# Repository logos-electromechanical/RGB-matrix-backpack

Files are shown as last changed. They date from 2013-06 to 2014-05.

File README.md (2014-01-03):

Logos RGB Matrix Backpack firmware, examples and docs
---------------------------

With the default firmware, this backpack is a board for driving 8x8 common anode RGB LED matrices from the I2C bus.

Remember that firmware memory is precious - you have *2 KB* of EEPROM and *128 bytes* of SRAM to work with on the backpack itself.

**Compilers:**

* AVR firmware is compiled with [WinAVR v20100110](http://sourceforge.net/projects/winavr/)

* Examples are compiled with [the Arduino IDE](http://arduino.cc/en/main/software)

**Hardware info:**

* [Holtek LED driver - HT1632C data sheet, FAQs and app notes](http://www.holtek.com/english/docum/consumer/1632c.htm)
	
* [Atmel MCU - ATtiny 2313V data sheet](http://www.atmel.com/Images/doc2543.pdf)

* [RGB LED common anode 8x8 matrix - ORM 2088RGB-5 data sheet](http://selfbuilt.net/datasheets/2088RGB-5-datasheet.jpg)

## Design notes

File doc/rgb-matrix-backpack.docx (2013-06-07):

| 9/28/2012

RGB LED Matrix I2C Backpack

Drive an 8x8 matrix of RGB LEDs over I2C
| | | Logos Electromechanical

# RGB LED Matrix I2C Backpack

Drive an 8x8 matrix of RGB LEDs over I2C

# Introduction

We recently found a good source of cheap 8x8 RGB LED common anode matrix displays. However, these displays have thirty-two pins (8 common anodes and 24 cathodes), which makes them painful to wire. Displaying any sort of image requires multiplexing, which consumes processor resources and programming time. We needed a better solution.

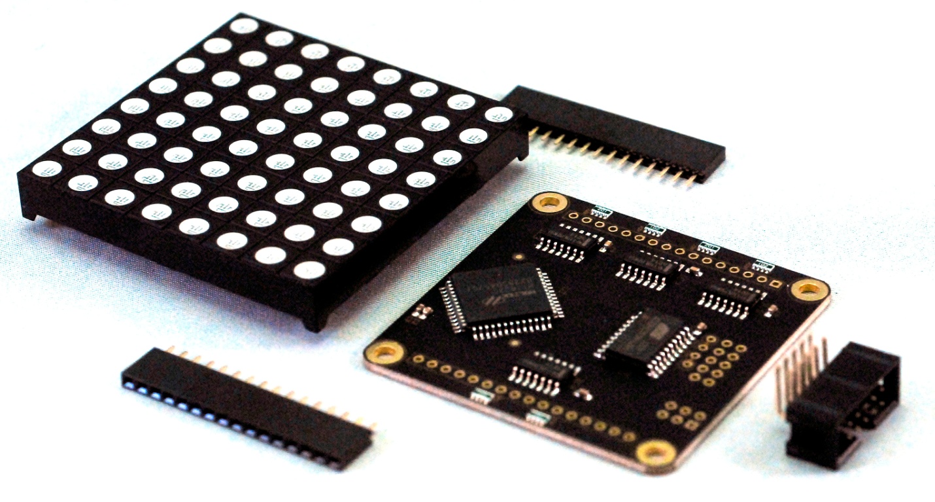
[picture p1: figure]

We were able to find a great driver chip that performs all of the required matrix functions. However, it speaks a strange dialect of SPI. Therefore, we added an ATtiny 2313 to provide an I2C interface that you can talk to with an Arduino or other microcontroller that has an I2C interface.

# Board Overview

The board contains eight integrated circuits – the ATtiny (U2) , the main driver chip (U1) and four hex inverters (IC1 – IC4) for driving the rows. The I2C interface connector solders on to the back of the board in order to avoid interfering with the display mounted to the front.

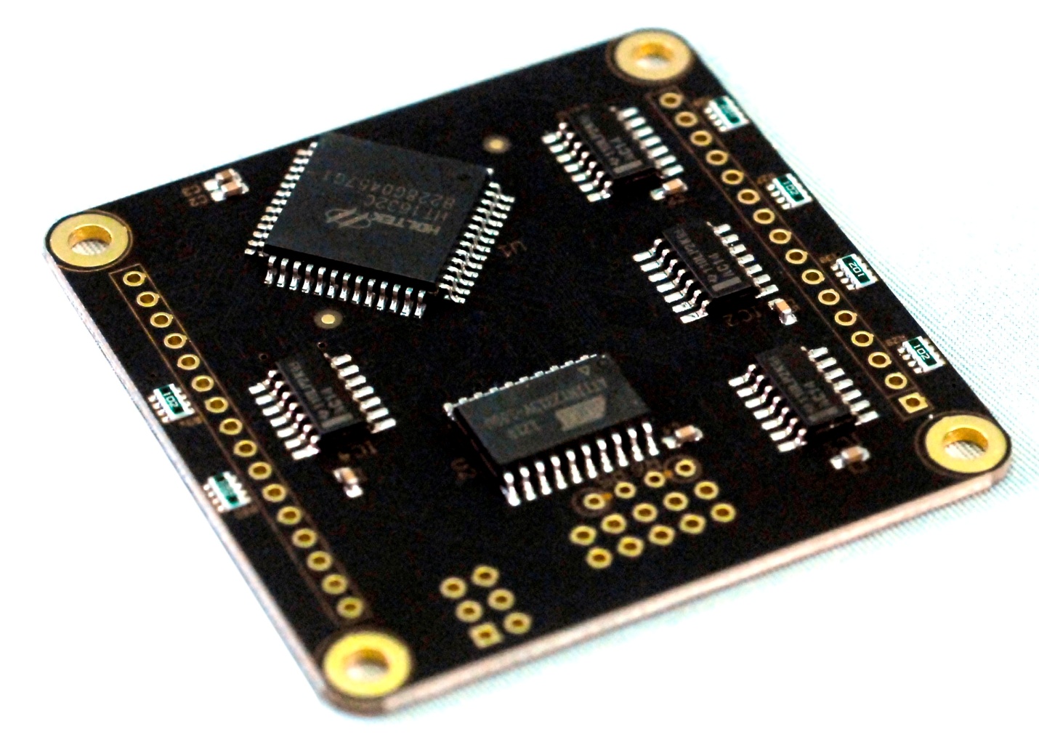
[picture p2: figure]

# Board Usage

## Assembly

- Insert the two sixteen pin female headers into the top (component) side of the board. This is most easily accomplished by plugging them into the RGB array and using that to align them upright. Solder them in place.
- Insert the ten pin male shrouded header into the back (no components) side of the board and solder it in place.
- Set the address as described below.

## Cable Pinout

The cable pinout is called out on the back side of the board. It is designed to interface with the line of I2C boards made by Snoot Labs, and therefore contains some pins that are extraneous to the use of this board.

Pin # | Pin Name | Pin Function
1-3 | 5V | Logic and LED power
4,6,8 | GND | Ground
5 | SDA | I2C Data
7 | SCL | I2C Clock
9-10 | 3V3 | Not connected

## Address Selection

The address is selected by the six jumpers on the back of the board. Depending on the desired value, the center terminal should be connected via a solder jumper to either the left (1) or right (0) terminal. These control the bottom six bits of the seven bit I2C address. The upper bit is always 1. Therefore, the possible I2C addresses range from binary b1000000 (hex 0x40) to binary b1111111 (hex 0x7f). If any jumper is left unmade, it defaults to a 1. Therefore, the default address of an otherwise un-configured board is 0x7f.

## Communication

Communication with the board is straightforward – send 24 bytes to the board over I2C. Each byte controls a single row of a single color. The first eight bytes control the red LEDs, the second eight bytes control the green LEDs, and the last eight bytes control the blue LEDs. The typical communication code under Arduino looks like this:

byte data[24];

Wire.beginTransmission(ADDRESS);

Wire.write(data, 24);

Wire.endTransmission();

This will transmit the contents of data to the board located at ADDRESS. The mapping of the transmitted bytes to the LEDs is as follows. Column numbers from the left, row numbers from the top.

Byte | MSB | Bit 6 | Bit 5 | Bit 4 | Bit 3 | Bit 2 | Bit 1 | LSB
0 | Red(0,0) | Red(1,0) | Red(2,0) | Red(3,0) | Red(4,0) | Red(5,0) | Red(6,0) | Red(7,0)
1 | Red(0,1) | Red(1,1) | Red(2,1) | Red(3,1) | Red(4,1) | Red(5,1) | Red(6,1) | Red(7,1)
2 | Red(0,2) | Red(1,2) | Red(2,2) | Red(3,2) | Red(4,2) | Red(5,2) | Red(6,2) | Red(7,2)
3 | Red(0,3) | Red(1,3) | Red(2,3) | Red(3,3) | Red(4,3) | Red(5,3) | Red(6,3) | Red(7,3)
4 | Red(0,4) | Red(1,4) | Red(2,4) | Red(3,4) | Red(4,4) | Red(5,4) | Red(6,4) | Red(7,4)
5 | Red(0,5) | Red(1,5) | Red(2,5) | Red(3,5) | Red(4,5) | Red(5,5) | Red(6,5) | Red(7,5)
6 | Red(0,6) | Red(1,6) | Red(2,6) | Red(3,6) | Red(4,6) | Red(5,6) | Red(6,6) | Red(7,6)
7 | Red(0,7) | Red(1,7) | Red(2,7) | Red(3,7) | Red(4,7) | Red(5,7) | Red(6,7) | Red(7,7)
8 | Green(0,7) | Green(1,7) | Green(2,7) | Green(3,7) | Green(4,7) | Green(5,7) | Green(6,7) | Green(7,7)
9 | Green(0,6) | Green(1,6) | Green(2,6) | Green(3,6) | Green(4,6) | Green(5,6) | Green(6,6) | Green(7,6)
10 | Green(0,5) | Green(1,5) | Green(2,5) | Green(3,5) | Green(4,5) | Green(5,5) | Green(6,5) | Green(7,5)
11 | Green(0,4) | Green(1,4) | Green(2,4) | Green(3,4) | Green(4,4) | Green(5,4) | Green(6,4) | Green(7,4)
12 | Green(0,3) | Green(1,3) | Green(2,3) | Green(3,3) | Green(4,3) | Green(5,3) | Green(6,3) | Green(7,3)
13 | Green(0,2) | Green(1,2) | Green(2,2) | Green(3,2) | Green(4,2) | Green(5,2) | Green(6,2) | Green(7,2)
13 | Green(0,1) | Green(1,1) | Green(2,1) | Green(3,1) | Green(4,1) | Green(5,1) | Green(6,1) | Green(7,1)
15 | Green(0,0) | Green(1,0) | Green(2,0) | Green(3,0) | Green(4,0) | Green(5,0) | Green(6,0) | Green(7,0)
16 | Blue(0,0) | Blue(1,0) | Blue(2,0) | Blue(3,0) | Blue(4,0) | Blue(5,0) | Blue(6,0) | Blue(7,0)
17 | Blue(0,1) | Blue(1,1) | Blue(2,1) | Blue(3,1) | Blue(4,1) | Blue(5,1) | Blue(6,1) | Blue(7,1)
18 | Blue(0,2) | Blue(1,2) | Blue(2,2) | Blue(3,2) | Blue(4,2) | Blue(5,2) | Blue(6,2) | Blue(7,2)
19 | Blue(0,3) | Blue(1,3) | Blue(2,3) | Blue(3,3) | Blue(4,3) | Blue(5,3) | Blue(6,3) | Blue(7,3)
20 | Blue(0,4) | Blue(1,4) | Blue(2,4) | Blue(3,4) | Blue(4,4) | Blue(5,4) | Blue(6,4) | Blue(7,4)
21 | Blue(0,5) | Blue(1,5) | Blue(2,5) | Blue(3,5) | Blue(4,5) | Blue(5,5) | Blue(6,5) | Blue(7,5)
22 | Blue(0,6) | Blue(1,6) | Blue(2,6) | Blue(3,6) | Blue(4,6) | Blue(5,6) | Blue(6,6) | Blue(7,6)
23 | Blue(0,7) | Blue(1,7) | Blue(2,7) | Blue(3,7) | Blue(4,7) | Blue(5,7) | Blue(6,7) | Blue(7,7)

4 © 2010 Logos Electromechanical CC-BY-NC-ND 3.0

5 © 2010 Logos Electromechanical CC-BY-NC-ND 3.0

Logos Electromechanical

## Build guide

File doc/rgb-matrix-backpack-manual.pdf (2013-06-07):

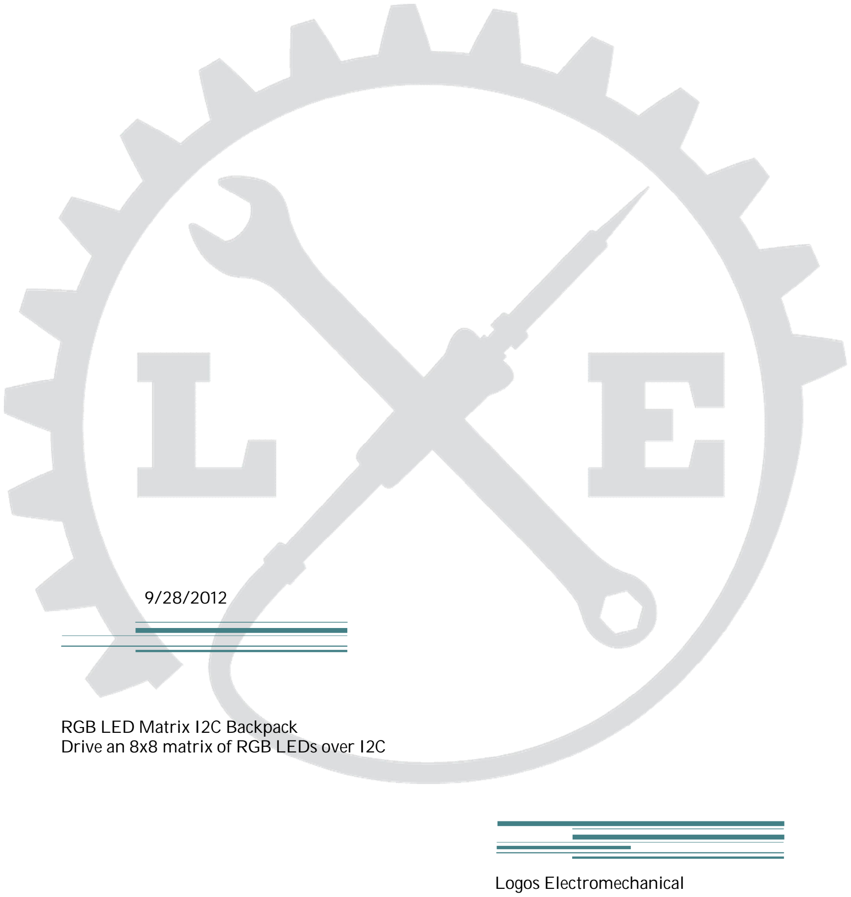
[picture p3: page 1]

9/28/2012

RGB LED Matrix I2C Backpack
Drive an 8x8 matrix of RGB LEDs over I2C

Logos Electromechanical

Logos Electromechanical

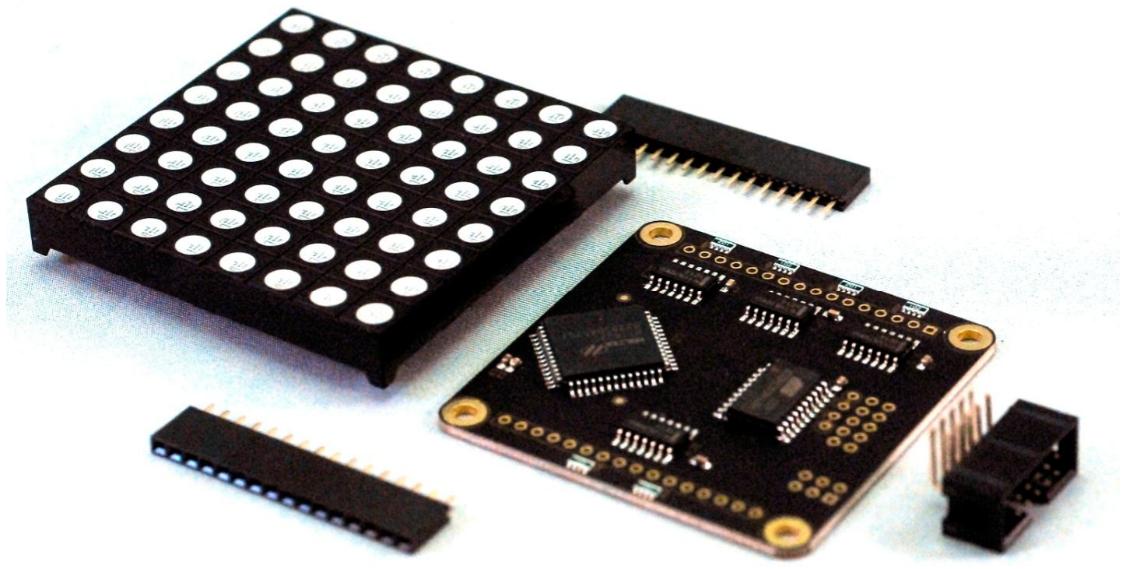
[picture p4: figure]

1

© 2010 Logos Electromechanical CC-BY-NC-ND 3.0

# RGB LED Matrix I2C Backpack

Drive an 8x8 matrix of RGB LEDs over I2C

## Introduction

We recently found a good source of cheap 8x8 RGB LED common anode matrix

displays. However, these displays have thirty-two pins (8 common anodes and 24

cathodes), which makes them painful to wire. Displaying any sort of image requires

multiplexing, which consumes processor resources and programming time. We needed

a better solution.

We were able to find a great driver chip that performs all of the required matrix

functions. However, it speaks a strange dialect of SPI. Therefore, we added an ATtiny

2313 to provide an I2C interface that you can talk to with an Arduino or other

microcontroller that has an I2C interface.

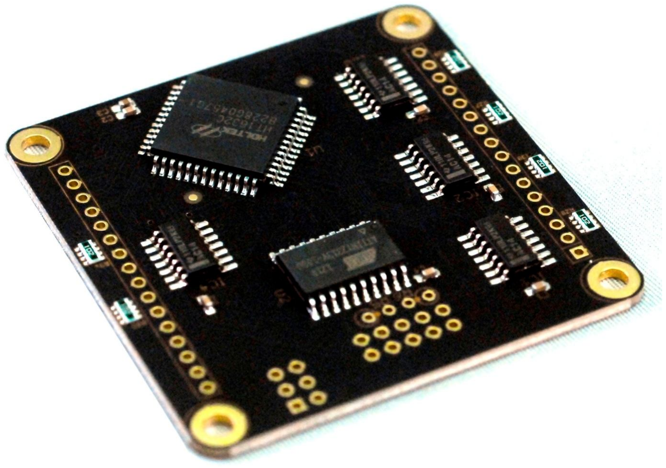
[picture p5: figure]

2

## Board Overview

The board contains eight integrated circuits – the ATtiny (U2) , the main driver chip

(U1) and four hex inverters (IC1 – IC4) for driving the rows. The I2C interface connector

solders on to the back of the board in order to avoid interfering with the display

mounted to the front.

3

## Board Usage

Assembly

- Insert the two sixteen pin female headers into the top (component) side of the

board. This is most easily accomplished by plugging them into the RGB array and

using that to align them upright. Solder them in place.

- Insert the ten pin male shrouded header into the back (no components) side of

the board and solder it in place.

- Set the address as described below.

Cable Pinout

The cable pinout is called out on the back side of the board. It is designed to interface

with the line of I2C boards made by Snoot Labs, and therefore contains some pins that

are extraneous to the use of this board.

Pin # | Pin Name | Pin Function
1-3 | 5V | Logic and LED power
4,6,8 | GND | Ground
5 | SDA | I2C Data
7 | SCL | I2C Clock
9-10 | 3V3 | Not connected

Address Selection

The address is selected by the six jumpers on the back of the board. Depending on the

desired value, the center terminal should be connected via a solder jumper to either the

left (1) or right (0) terminal. These control the bottom six bits of the seven bit I2C

address. The upper bit is always 1. Therefore, the possible I2C addresses range from

binary b1000000 (hex 0x40) to binary b1111111 (hex 0x7f). If any jumper is left unmade,

4

it defaults to a 1. Therefore, the default address of an otherwise un-configured board is

0x7f.

Communication

Communication with the board is straightforward – send 24 bytes to the board over I2C.

Each byte controls a single row of a single color. The first eight bytes control the red

LEDs, the second eight bytes control the green LEDs, and the last eight bytes control the

blue LEDs. The typical communication code under Arduino looks like this:

byte data[24];

Wire.beginTransmission(ADDRESS);

Wire.write(data, 24);

Wire.endTransmission();

This will transmit the contents of data to the board located at ADDRESS. The mapping

of the transmitted bytes to the LEDs is as follows. Column numbers from the left, row

numbers from the top.

Byte MSB | Bit 6 | Bit 5 | Bit 4 | Bit 3 | Bit 2 | Bit 1 | LSB
0 | Red(0,0) | Red(1,0) | Red(2,0) | Red(3,0) | Red(4,0) | Red(5,0) | Red(6,0) | Red(7,0)
1 | Red(0,1) | Red(1,1) | Red(2,1) | Red(3,1) | Red(4,1) | Red(5,1) | Red(6,1) | Red(7,1)
2 | Red(0,2) | Red(1,2) | Red(2,2) | Red(3,2) | Red(4,2) | Red(5,2) | Red(6,2) | Red(7,2)
3 | Red(0,3) | Red(1,3) | Red(2,3) | Red(3,3) | Red(4,3) | Red(5,3) | Red(6,3) | Red(7,3)
4 | Red(0,4) | Red(1,4) | Red(2,4) | Red(3,4) | Red(4,4) | Red(5,4) | Red(6,4) | Red(7,4)
5 | Red(0,5) | Red(1,5) | Red(2,5) | Red(3,5) | Red(4,5) | Red(5,5) | Red(6,5) | Red(7,5)
6 | Red(0,6) | Red(1,6) | Red(2,6) | Red(3,6) | Red(4,6) | Red(5,6) | Red(6,6) | Red(7,6)
7 | Red(0,7) | Red(1,7) | Red(2,7) | Red(3,7) | Red(4,7) | Red(5,7) | Red(6,7) | Red(7,7)
8 | Green(0,7) Green(1,7) Green(2,7) Green(3,7) Green(4,7) Green(5,7) Green(6,7) Green(7,7)

5

Byte MSB | Bit 6 | Bit 5 | Bit 4 | Bit 3 | Bit 2 | Bit 1 | LSB
9 | Green(0,6) Green(1,6) Green(2,6) Green(3,6) Green(4,6) Green(5,6) Green(6,6) Green(7,6)
10 | Green(0,5) Green(1,5) Green(2,5) Green(3,5) Green(4,5) Green(5,5) Green(6,5) Green(7,5)
11 | Green(0,4) Green(1,4) Green(2,4) Green(3,4) Green(4,4) Green(5,4) Green(6,4) Green(7,4)
12 | Green(0,3) Green(1,3) Green(2,3) Green(3,3) Green(4,3) Green(5,3) Green(6,3) Green(7,3)
13 | Green(0,2) Green(1,2) Green(2,2) Green(3,2) Green(4,2) Green(5,2) Green(6,2) Green(7,2)
13 | Green(0,1) Green(1,1) Green(2,1) Green(3,1) Green(4,1) Green(5,1) Green(6,1) Green(7,1)
15 | Green(0,0) Green(1,0) Green(2,0) Green(3,0) Green(4,0) Green(5,0) Green(6,0) Green(7,0)
16 | Blue(0,0) | Blue(1,0) | Blue(2,0) | Blue(3,0) | Blue(4,0) | Blue(5,0) | Blue(6,0) | Blue(7,0)
17 | Blue(0,1) | Blue(1,1) | Blue(2,1) | Blue(3,1) | Blue(4,1) | Blue(5,1) | Blue(6,1) | Blue(7,1)
18 | Blue(0,2) | Blue(1,2) | Blue(2,2) | Blue(3,2) | Blue(4,2) | Blue(5,2) | Blue(6,2) | Blue(7,2)
19 | Blue(0,3) | Blue(1,3) | Blue(2,3) | Blue(3,3) | Blue(4,3) | Blue(5,3) | Blue(6,3) | Blue(7,3)
20 | Blue(0,4) | Blue(1,4) | Blue(2,4) | Blue(3,4) | Blue(4,4) | Blue(5,4) | Blue(6,4) | Blue(7,4)
21 | Blue(0,5) | Blue(1,5) | Blue(2,5) | Blue(3,5) | Blue(4,5) | Blue(5,5) | Blue(6,5) | Blue(7,5)
22 | Blue(0,6) | Blue(1,6) | Blue(2,6) | Blue(3,6) | Blue(4,6) | Blue(5,6) | Blue(6,6) | Blue(7,6)
23 | Blue(0,7) | Blue(1,7) | Blue(2,7) | Blue(3,7) | Blue(4,7) | Blue(5,7) | Blue(6,7) | Blue(7,7)

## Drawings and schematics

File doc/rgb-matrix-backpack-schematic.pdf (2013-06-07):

## ABCDE

## ABCDE

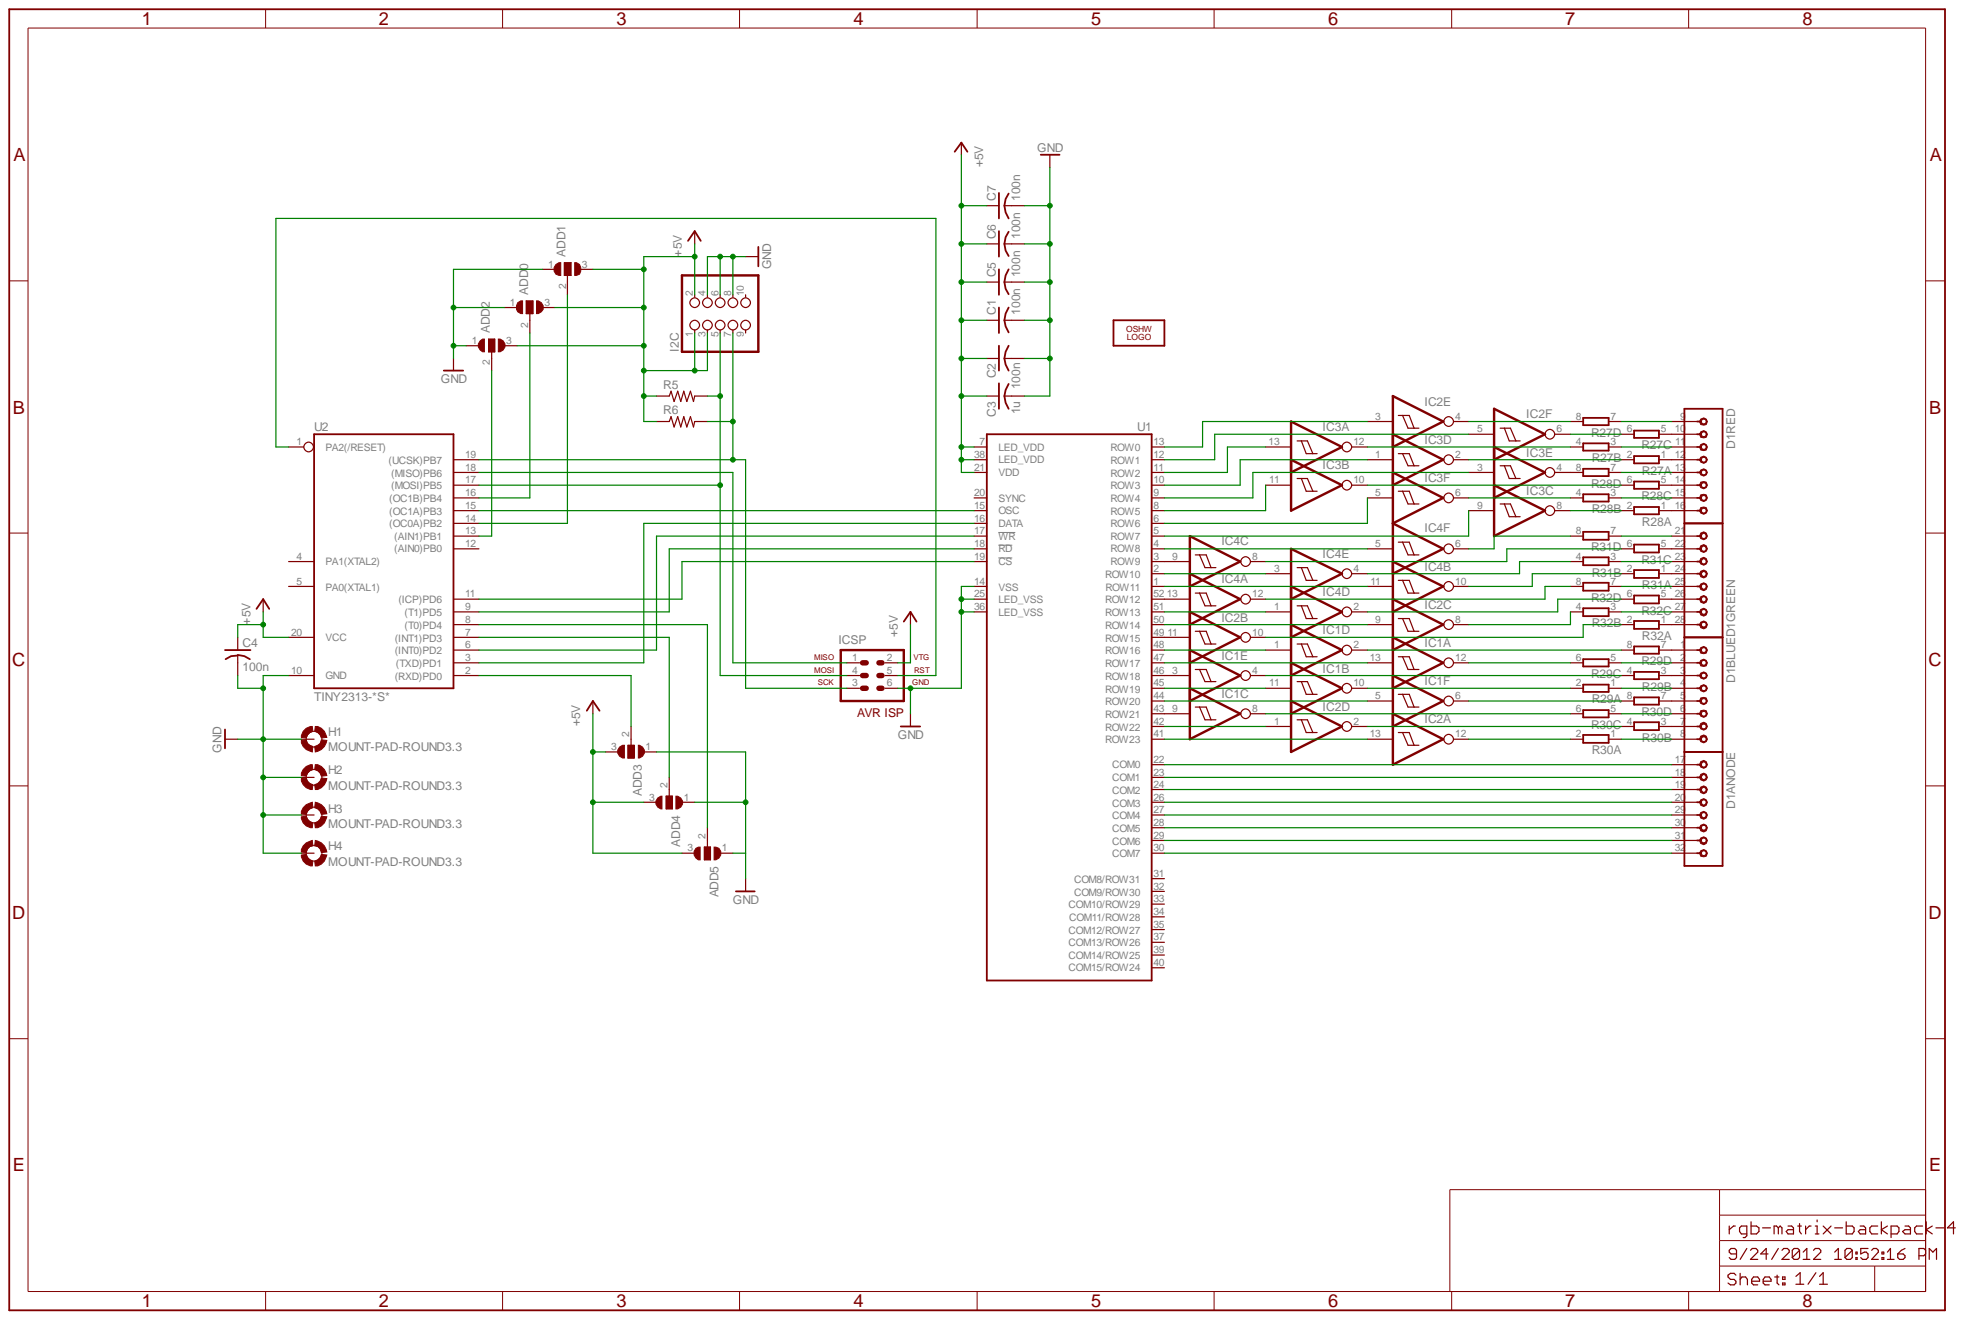
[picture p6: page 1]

3 9 | 8 | IC4E
1 | IC4A
13 | 12 | IC4D

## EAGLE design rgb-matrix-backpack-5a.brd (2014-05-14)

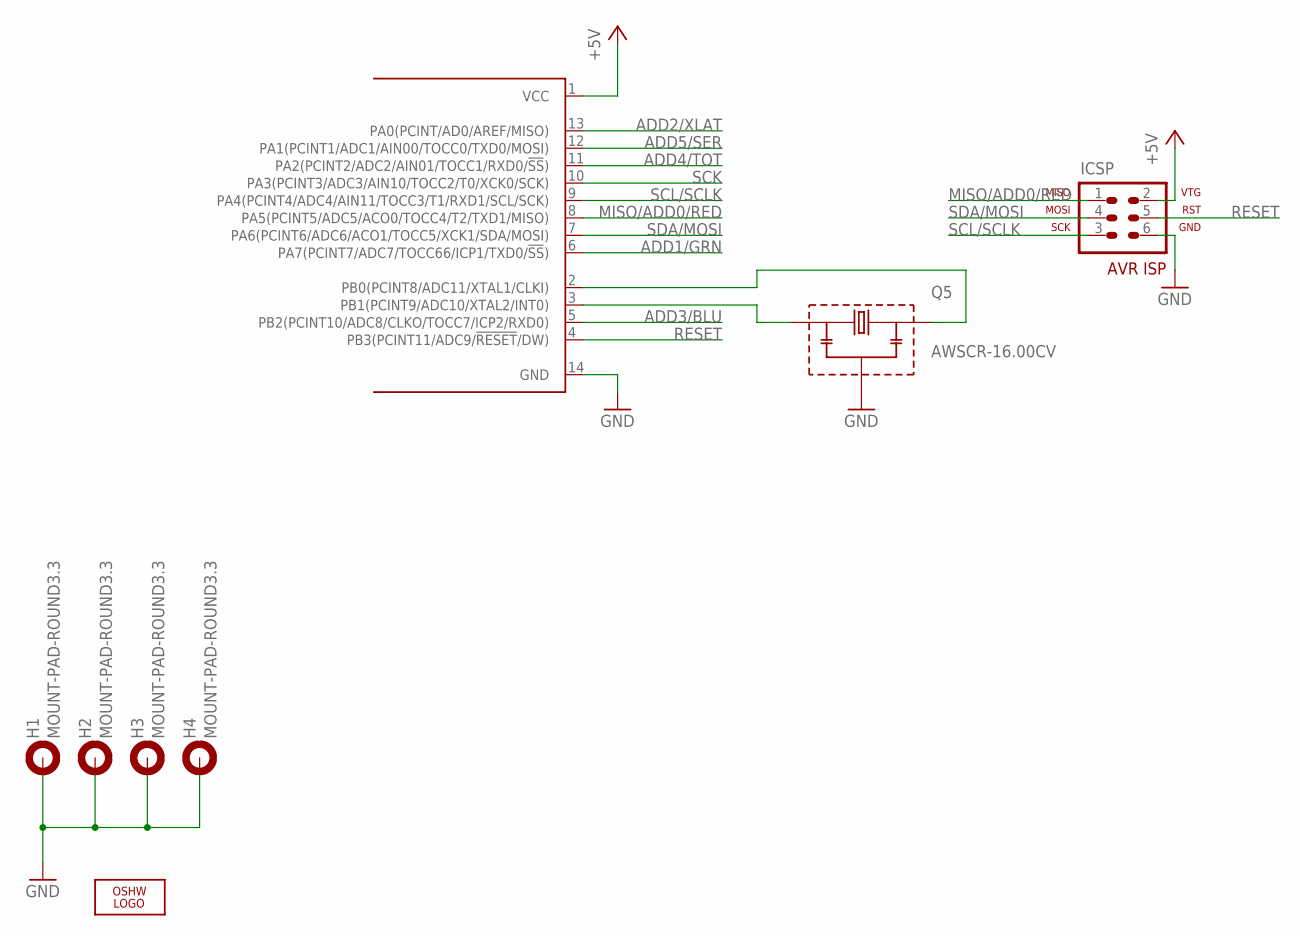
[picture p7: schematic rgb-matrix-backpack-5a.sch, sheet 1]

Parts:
H1, H2, H3, H4: MOUNT-PAD-ROUND3.3; 3,3-PAD
ICSP: AVR-ISP-6
LOGO1: OSHW_LOGO_FILLX0350-NT; OSHW_FILLX350_NOTEXT
Q5: AWSCR-16.00CV; AWSCR
U1: ATTINY841-SU; SO14

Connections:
ADD1/GRN: U1.6 (PA7(PCINT7/ADC7/TOCC66/ICP1/TXD0/!SS!)); also elsewhere on the board
ADD2/XLAT: U1.13 (PA0(PCINT/AD0/AREF/MISO)); also elsewhere on the board
ADD3/BLU: U1.5 (PB2(PCINT10/ADC8/CLKO/TOCC7/ICP2/RXD0)); also elsewhere on the board
ADD4/TOT: U1.11 (PA2(PCINT2/ADC2/AIN01/TOCC1/RXD0/!SS!)); also elsewhere on the board
ADD5/SER: U1.12 (PA1(PCINT1/ADC1/AIN00/TOCC0/TXD0/MOSI)); also elsewhere on the board
GND: H1.B3,3, H2.B3,3, H3.B3,3, H4.B3,3, ICSP.6, Q5.2, U1.14 (GND); also elsewhere on the board
MISO/ADD0/RED: ICSP.1, U1.8 (PA5(PCINT5/ADC5/ACO0/TOCC4/T2/TXD1/MISO)); also elsewhere on the board
unnamed: Q5.1, U1.3 (PB1(PCINT9/ADC10/XTAL2/INT0))
unnamed: Q5.3, U1.2 (PB0(PCINT8/ADC11/XTAL1/CLKI))
RESET: ICSP.5, U1.4 (PB3(PCINT11/ADC9/!RESET!/DW))
SCK: U1.10 (PA3(PCINT3/ADC3/AIN10/TOCC2/T0/XCK0/SCK)); also elsewhere on the board
SCL/SCLK: ICSP.3, U1.9 (PA4(PCINT4/ADC4/AIN11/TOCC3/T1/RXD1/SCL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); also elsewhere on the board
SDA/MOSI: ICSP.4, U1.7 (PA6(PCINT6/ADC6/ACO1/TOCC5/XCK1/SDA/MOS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); also elsewhere on the board
VCC: ICSP.2, U1.1 (VCC); also elsewhere on the board

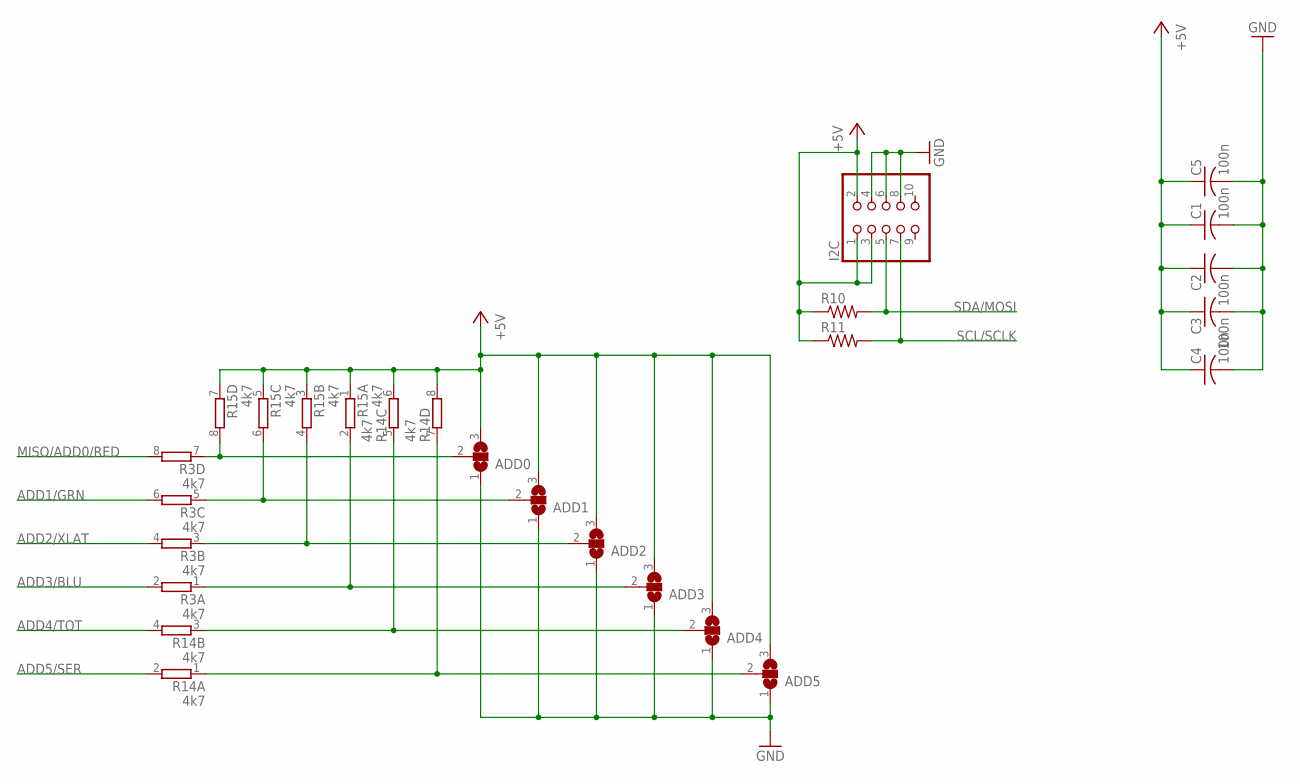
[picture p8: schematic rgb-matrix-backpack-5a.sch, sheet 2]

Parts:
ADD0, ADD1, ADD2, ADD3, ADD4, ADD5: SJ2W; SJ_2
C1, C2, C4, C5: 100n; C0603; PARTNO CC0603MRY5V9BB104
C3: 100n; C0603; PARTNO CC0603ZRY5V7BB105
I2C: PINHD-2X5_2.54-90°; 2X05/90
R3, R14, R15: 4k7; CTS742C083-RES; PARTNO 742C083102JPTR
R10, R11: R-US_0207/2V; 0207/2V; PARTNO CF14JT4K70

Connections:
ADD1/GRN: R3.6 (2); also elsewhere on the board
ADD2/XLAT: R3.4 (2); also elsewhere on the board
ADD3/BLU: R3.2; also elsewhere on the board
ADD4/TOT: R14.4 (2); also elsewhere on the board
ADD5/SER: R14.2; also elsewhere on the board
GND: ADD0.1, ADD1.1, ADD2.1, ADD3.1, ADD4.1, ADD5.1, C1.2, C2.2, C3.2, C4.2, C5.2, I2C.4, I2C.6, I2C.8; also elsewhere on the board
MISO/ADD0/RED: R3.8 (2); also elsewhere on the board
unnamed: ADD3.2, R3.1, R15.2
unnamed: ADD2.2, R3.3 (1), R15.4 (2)
unnamed: ADD0.2, R3.7 (1), R15.8 (2)
unnamed: ADD1.2, R3.5 (1), R15.6 (2)
unnamed: ADD4.2, R14.3 (1), R14.5 (1)
unnamed: ADD5.2, R14.1, R14.7 (1)
SCL/SCLK: I2C.7, R11.2; also elsewhere on the board
SDA/MOSI: I2C.5, R10.2; also elsewhere on the board
VCC: ADD0.3, ADD1.3, ADD2.3, ADD3.3, ADD4.3, ADD5.3, C1.1, C2.1, C3.1, C4.1, C5.1, I2C.1, I2C.2, I2C.3, R10.1, R11.1, R14.6 (2), R14.8 (2), R15.1, R15.3 (1), R15.5 (1), R15.7 (1); also elsewhere on the board

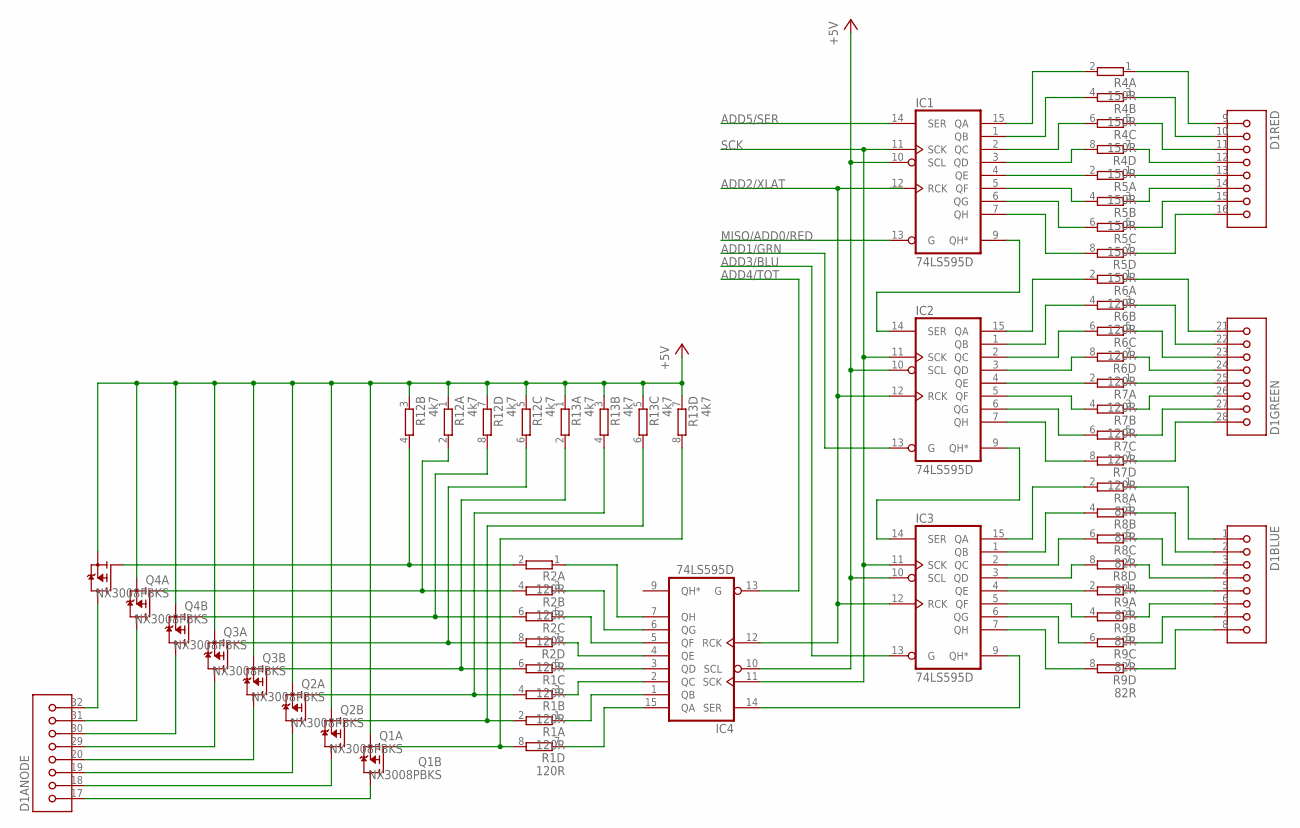
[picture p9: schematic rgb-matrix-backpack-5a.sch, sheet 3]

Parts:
D1: 60MM-8X8-RGB-LED-ARRAY; 60MM-8X8-RGB-MATRIX
IC1, IC2, IC3, IC4: 74LS595D; SO16
Q1: NX3008PBKS; SOT363_INFINEON; PARTNO NX3008PBKS
Q2, Q3, Q4: NX3008PBKS; SOT363_INFINEON
R1, R2, R6, R7: 120R; CTS742C083-RES; PARTNO 742C083102JPTR
R4, R5: 150R; CTS742C083-RES; PARTNO 742C083102JPTR
R8, R9: 82R; CTS742C083-RES; PARTNO 742C083102JPTR
R12, R13: 4k7; CTS742C083-RES; PARTNO 742C083102JPTR

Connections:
ADD1/GRN: IC2.13 (G); also elsewhere on the board
ADD2/XLAT: IC1.12 (RCK), IC2.12 (RCK), IC3.12 (RCK), IC4.12 (RCK); also elsewhere on the board
ADD3/BLU: IC3.13 (G); also elsewhere on the board
ADD4/TOT: IC4.13 (G); also elsewhere on the board
ADD5/SER: IC1.14 (SER); also elsewhere on the board
GND: IC1.8 (GND), IC2.8 (GND), IC3.8 (GND), IC4.8 (GND); also elsewhere on the board
MISO/ADD0/RED: IC1.13 (G); also elsewhere on the board
unnamed: D1.9 (1), R4.1
unnamed: D1.10 (2), R4.3 (1)
unnamed: D1.11 (3), R4.5 (1)
unnamed: D1.12 (4), R4.7 (1)
unnamed: D1.13 (5), R5.1
unnamed: D1.14 (6), R5.3 (1)
unnamed: D1.15 (7), R5.5 (1)
unnamed: D1.16 (8), R5.7 (1)
unnamed: D1.1, R8.1
unnamed: D1.2, R8.3 (1)
unnamed: D1.3, R8.5 (1)
unnamed: D1.4, R8.7 (1)
unnamed: D1.5, R9.1
unnamed: D1.6, R9.3 (1)
unnamed: D1.7, R9.5 (1)
unnamed: D1.8, R9.7 (1)
unnamed: D1.21 (8), R6.1
unnamed: D1.22 (7), R6.3 (1)
unnamed: D1.23 (6), R6.5 (1)
unnamed: D1.24 (5), R6.7 (1)
unnamed: D1.25 (4), R7.1
unnamed: D1.26 (3), R7.3 (1)
unnamed: D1.27 (2), R7.5 (1)
unnamed: D1.28 (1), R7.7 (1)
unnamed: IC3.9 (QH*), IC4.14 (SER)
unnamed: IC1.15 (QA), R4.2
unnamed: IC1.2 (QC), R4.6 (2)
unnamed: IC1.4 (QE), R5.2
unnamed: IC1.6 (QG), R5.6 (2)
unnamed: IC2.15 (QA), R6.2
unnamed: IC2.2 (QC), R6.6 (2)
unnamed: IC2.4 (QE), R7.2
unnamed: IC2.6 (QG), R7.6 (2)
unnamed: IC3.1 (QB), R8.4 (2)
unnamed: IC3.3 (QD), R8.8 (2)
unnamed: IC3.5 (QF), R9.4 (2)
unnamed: IC3.7 (QH), R9.8 (2)
unnamed: IC1.3 (QD), R4.8 (2)
unnamed: IC1.5 (QF), R5.4 (2)
unnamed: IC2.1 (QB), R6.4 (2)
unnamed: IC2.3 (QD), R6.8 (2)
unnamed: IC2.5 (QF), R7.4 (2)
unnamed: IC2.7 (QH), R7.8 (2)
unnamed: IC3.15 (QA), R8.2
unnamed: IC3.2 (QC), R8.6 (2)
unnamed: IC3.4 (QE), R9.2
unnamed: IC3.6 (QG), R9.6 (2)
unnamed: IC4.15 (QA), R1.7 (1)
unnamed: IC4.1 (QB), R1.1
unnamed: IC4.2 (QC), R1.3 (1)
unnamed: IC4.3 (QD), R1.5 (1)
unnamed: Q1.5 (G), R1.8 (2), R13.8 (2)
unnamed: IC1.7 (QH), R5.8 (2)
unnamed: Q1.2 (G), R1.2, R13.6 (2)
unnamed: IC1.9 (QH*), IC2.14 (SER)
unnamed: IC2.9 (QH*), IC3.14 (SER)
unnamed: Q2.2 (G), R1.6 (2), R13.2
unnamed: Q2.5 (G), R1.4 (2), R13.4 (2)
unnamed: IC1.1 (QB), R4.4 (2)
unnamed: D1.20 (4), Q2.6 (D)
unnamed: D1.19 (3), Q2.3 (D)
unnamed: D1.18 (2), Q1.6 (D)
unnamed: D1.17 (1), Q1.3 (D)
unnamed: D1.29 (5), Q3.3 (D)
unnamed: D1.30 (6), Q3.6 (D)
unnamed: D1.31 (7), Q4.3 (D)
unnamed: D1.32 (8), Q4.6 (D)
unnamed: IC4.4 (QE), R2.7 (1)
unnamed: IC4.5 (QF), R2.5 (1)
unnamed: IC4.6 (QG), R2.3 (1)
unnamed: IC4.7 (QH), R2.1
unnamed: Q4.2 (G), R2.2, R12.4 (2)
unnamed: Q4.5 (G), R2.4 (2), R12.2
unnamed: Q3.2 (G), R2.6 (2), R12.8 (2)
unnamed: Q3.5 (G), R2.8 (2), R12.6 (2)
SCK: IC1.11 (SCK), IC2.11 (SCK), IC3.11 (SCK), IC4.11 (SCK); also elsewhere on the board
VCC: IC1.10 (SCL), IC1.16 (VCC), IC2.10 (SCL), IC2.16 (VCC), IC3.10 (SCL), IC3.16 (VCC), IC4.10 (SCL), IC4.16 (VCC), Q1.1 (S), Q1.4 (S), Q2.1 (S), Q2.4 (S), Q3.1 (S), Q3.4 (S), Q4.1 (S), Q4.4 (S), R12.1, R12.3 (1), R12.5 (1), R12.7 (1), R13.1, R13.3 (1), R13.5 (1), R13.7 (1); also elsewhere on the board

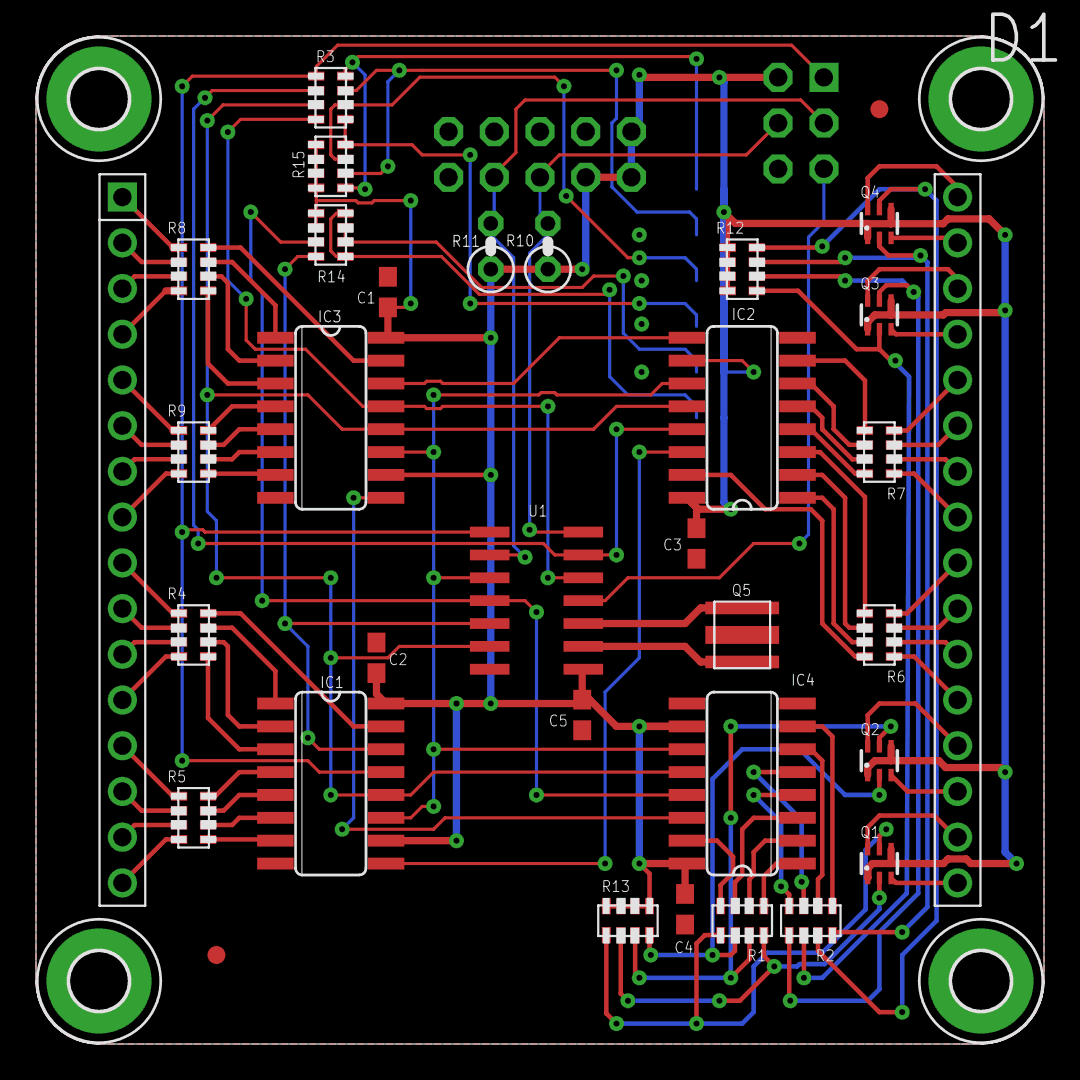
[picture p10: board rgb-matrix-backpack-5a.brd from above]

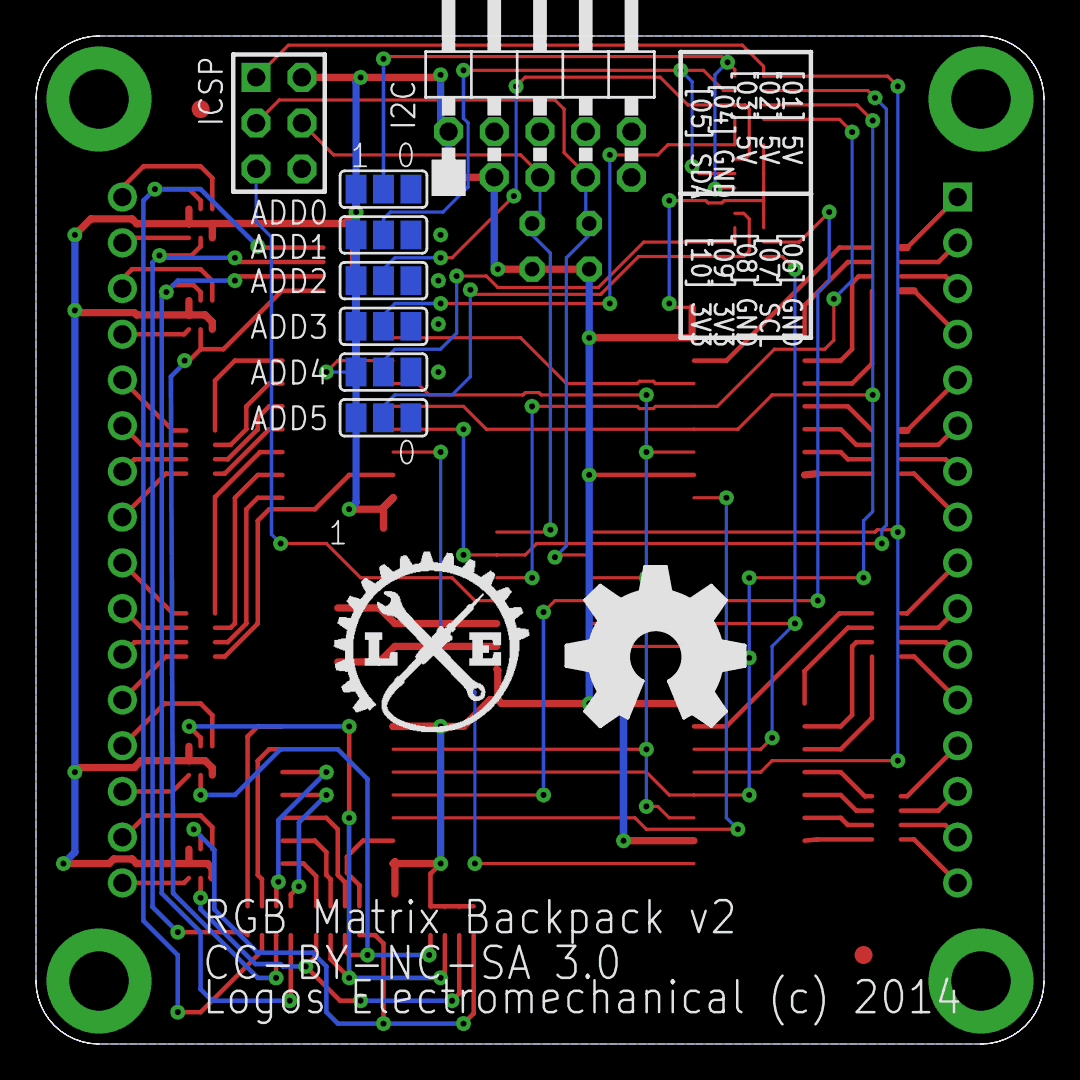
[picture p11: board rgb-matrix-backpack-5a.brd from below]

Board: 2 copper layers, 56.0 x 56.0 mm, 47 parts (10 on the bottom side), 95 nets.

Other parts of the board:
U$1: LOGO-SM
U$4, U$5: FIDUCIAL_G10

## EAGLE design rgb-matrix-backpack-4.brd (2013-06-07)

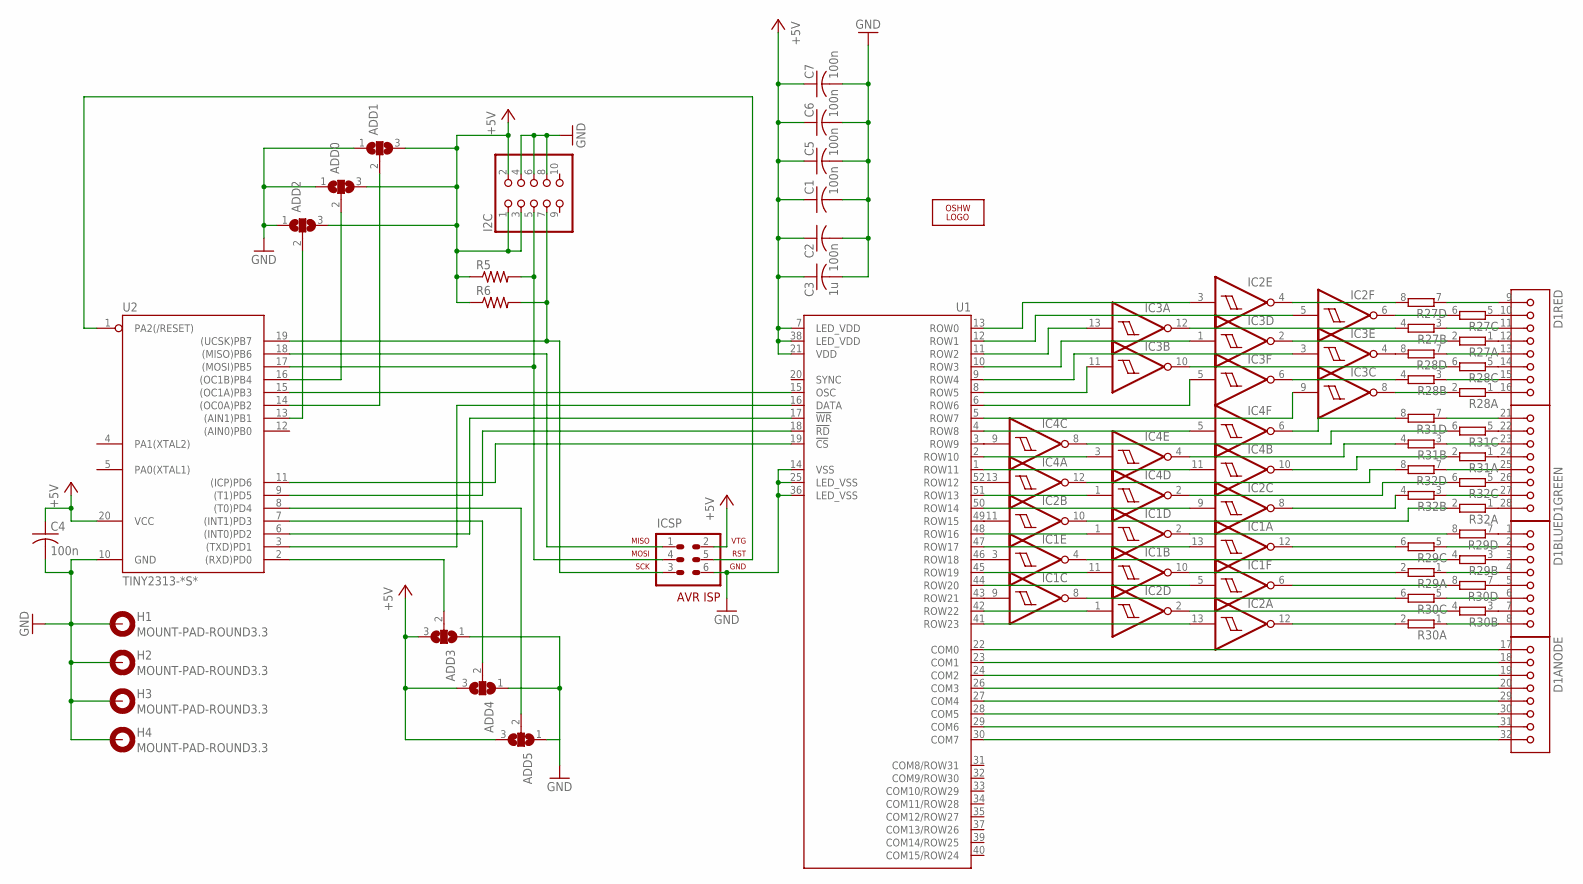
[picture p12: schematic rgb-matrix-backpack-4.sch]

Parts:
ADD0, ADD1, ADD2, ADD3, ADD4, ADD5: SJ2W; SJ_2
C1, C2, C4, C5, C6, C7: 100n; C0603; PARTNO CC0603MRY5V9BB104
C3: 1u; C0603; PARTNO CC0603ZRY5V7BB105
D1: 60MM-8X8-RGB-LED-ARRAY; 60MM-8X8-RGB-MATRIX
H1, H2, H3, H4: MOUNT-PAD-ROUND3.3; 3,3-PAD
I2C: PINHD-2X5_2.54-90°; 2X05/90
IC1, IC2, IC3, IC4: 74AC14D; SO14; PARTNO SN74AC14D
ICSP: AVR-ISP-6
LOGO1: OSHW_LOGO_FILLX0350-NT; OSHW_FILLX350_NOTEXT
R5, R6: R-US_0207/2V; 0207/2V; PARTNO CF14JT4K70
R27, R28, R29, R30, R31, R32: 4R-NCTS742C083; CTS742C083-RES; PARTNO 742C083102JPTR
U1: HT1632C; QFP52_SOT379-1; PARTNO HT1632C
U2: TINY2313-*S*; SO20L$; PARTNO ATTINY2313V-10SU

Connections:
GND: ADD0.1, ADD1.1, ADD2.1, ADD3.1, ADD4.1, ADD5.1, C1.2, C2.2, C3.2, C4.2, C5.2, C6.2, C7.2, H1.B3,3, H2.B3,3, H3.B3,3, H4.B3,3, I2C.4, I2C.6, I2C.8, IC1.7 (GND), IC2.7 (GND), IC3.7 (GND), IC4.7 (GND), ICSP.6, U1.14 (VSS), U1.25 (LED_VSS), U1.36 (LED_VSS), U2.10 (GND)
unnamed: D1.9 (1), R27.7 (1)
unnamed: D1.10 (2), R27.5 (1)
unnamed: D1.11 (3), R27.3 (1)
unnamed: D1.12 (4), R27.1
unnamed: D1.13 (5), R28.7 (1)
unnamed: D1.14 (6), R28.5 (1)
unnamed: D1.15 (7), R28.3 (1)
unnamed: D1.16 (8), R28.1
unnamed: D1.1, R29.7 (1)
unnamed: D1.2, R29.5 (1)
unnamed: D1.3, R29.3 (1)
unnamed: D1.4, R29.1
unnamed: D1.5, R30.7 (1)
unnamed: D1.6, R30.5 (1)
unnamed: D1.7, R30.3 (1)
unnamed: D1.8, R30.1
unnamed: D1.21 (8), R31.7 (1)
unnamed: D1.22 (7), R31.5 (1)
unnamed: D1.23 (6), R31.3 (1)
unnamed: D1.24 (5), R31.1
unnamed: D1.25 (4), R32.7 (1)
unnamed: D1.26 (3), R32.5 (1)
unnamed: D1.27 (2), R32.3 (1)
unnamed: D1.28 (1), R32.1
unnamed: D1.17 (1), U1.22 (COM0)
unnamed: D1.18 (2), U1.23 (COM1)
unnamed: D1.19 (3), U1.24 (COM2)
unnamed: ICSP.1, U2.18 ((MISO)PB6)
unnamed: U1.15 (OSC), U2.15 ((OC1A)PB3)
unnamed: D1.20 (4), U1.26 (COM3)
unnamed: ICSP.5, U2.1 (PA2(/RESET))
unnamed: IC2.12 (O), R30.2
unnamed: D1.29 (5), U1.27 (COM4)
unnamed: ADD3.2, U2.2 ((RXD)PD0)
unnamed: ADD4.2, U2.7 ((INT1)PD3)
unnamed: I2C.5, ICSP.4, R5.2, U2.17 ((MOSI)PB5)
unnamed: I2C.7, ICSP.3, R6.2, U2.19 ((UCSK)PB7)
unnamed: D1.30 (6), U1.28 (COM5)
unnamed: ADD5.2, U2.8 ((T0)PD4)
unnamed: D1.31 (7), U1.29 (COM6)
unnamed: D1.32 (8), U1.30 (COM7)
unnamed: IC2.2 (O), R30.4 (2)
unnamed: IC1.8 (O), R30.6 (2)
unnamed: IC1.6 (O), R30.8 (2)
unnamed: IC1.10 (O), R29.2
unnamed: IC1.4 (O), R29.4 (2)
unnamed: IC1.12 (O), R29.6 (2)
unnamed: U1.16 (DATA), U2.3 ((TXD)PD1)
unnamed: U1.17 (!WR!), U2.6 ((INT0)PD2)
unnamed: U1.18 (!RD!), U2.9 ((T1)PD5)
unnamed: U1.19 (!CS!), U2.11 ((ICP)PD6)
unnamed: IC1.2 (O), R29.8 (2)
unnamed: IC3.8 (O), R28.2
unnamed: IC3.6 (O), R28.4 (2)
unnamed: IC3.10 (O), R28.6 (2)
unnamed: IC3.4 (O), R28.8 (2)
unnamed: IC3.2 (O), R27.2
unnamed: IC3.12 (O), R27.4 (2)
unnamed: IC2.6 (O), R27.6 (2)
unnamed: IC2.4 (O), R27.8 (2)
unnamed: IC4.8 (O), R31.6 (2)
unnamed: IC4.6 (O), R31.8 (2)
unnamed: IC4.4 (O), R31.4 (2)
unnamed: IC4.10 (O), R31.2
unnamed: IC4.12 (O), R32.8 (2)
unnamed: IC4.2 (O), R32.6 (2)
unnamed: IC2.8 (O), R32.4 (2)
unnamed: IC2.10 (O), R32.2
unnamed: IC3.1 (I), U1.10 (ROW3)
unnamed: IC3.9 (I), U1.5 (ROW7)
unnamed: IC3.5 (I), U1.6 (ROW6)
unnamed: IC3.11 (I), U1.8 (ROW5)
unnamed: ADD2.2, U2.13 ((AIN1)PB1)
unnamed: IC3.3 (I), U1.9 (ROW4)
unnamed: IC3.13 (I), U1.11 (ROW2)
unnamed: IC2.5 (I), U1.12 (ROW1)
unnamed: ADD0.2, U2.16 ((OC1B)PB4)
unnamed: ADD1.2, U2.14 ((OC0A)PB2)
unnamed: IC2.3 (I), U1.13 (ROW0)
unnamed: IC2.13 (I), U1.41 (ROW23)
unnamed: IC2.1 (I), U1.42 (ROW22)
unnamed: IC1.9 (I), U1.43 (ROW21)
unnamed: IC1.3 (I), U1.46 (ROW18)
unnamed: IC1.11 (I), U1.45 (ROW19)
unnamed: IC1.5 (I), U1.44 (ROW20)
unnamed: IC1.13 (I), U1.47 (ROW17)
unnamed: IC1.1 (I), U1.48 (ROW16)
unnamed: IC4.3 (I), U1.2 (ROW10)
unnamed: IC4.5 (I), U1.4 (ROW8)
unnamed: IC4.9 (I), U1.3 (ROW9)
unnamed: IC4.11 (I), U1.1 (ROW11)
unnamed: IC4.13 (I), U1.52 (ROW12)
unnamed: IC4.1 (I), U1.51 (ROW13)
unnamed: IC2.9 (I), U1.50 (ROW14)
unnamed: IC2.11 (I), U1.49 (ROW15)
VCC: ADD0.3, ADD1.3, ADD2.3, ADD3.3, ADD4.3, ADD5.3, C1.1, C2.1, C3.1, C4.1, C5.1, C6.1, C7.1, I2C.1, I2C.2, I2C.3, IC1.14 (VCC), IC2.14 (VCC), IC3.14 (VCC), IC4.14 (VCC), ICSP.2, R5.1, R6.1, U1.7 (LED_VDD), U1.21 (VDD), U1.38 (LED_VDD), U2.20 (VCC)

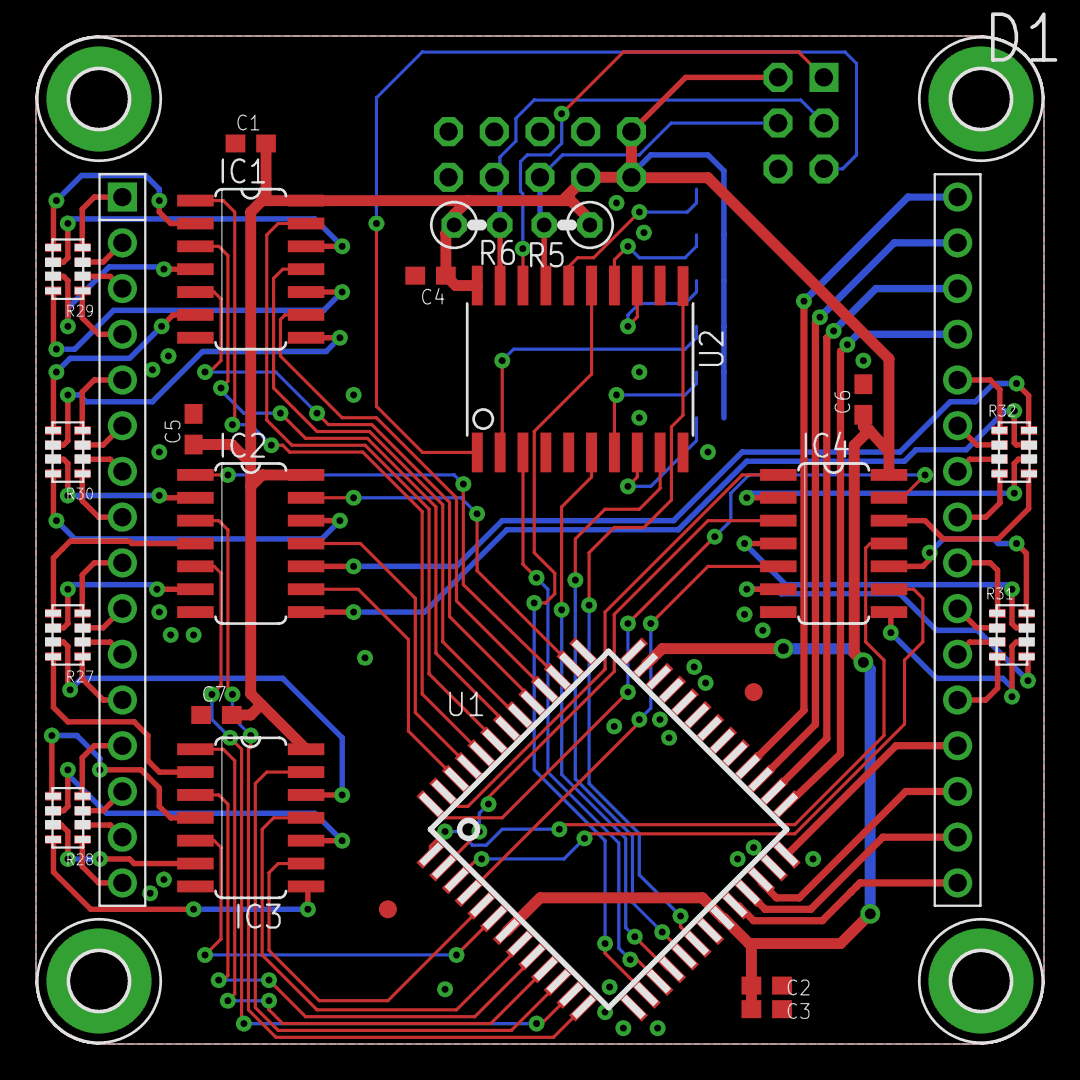
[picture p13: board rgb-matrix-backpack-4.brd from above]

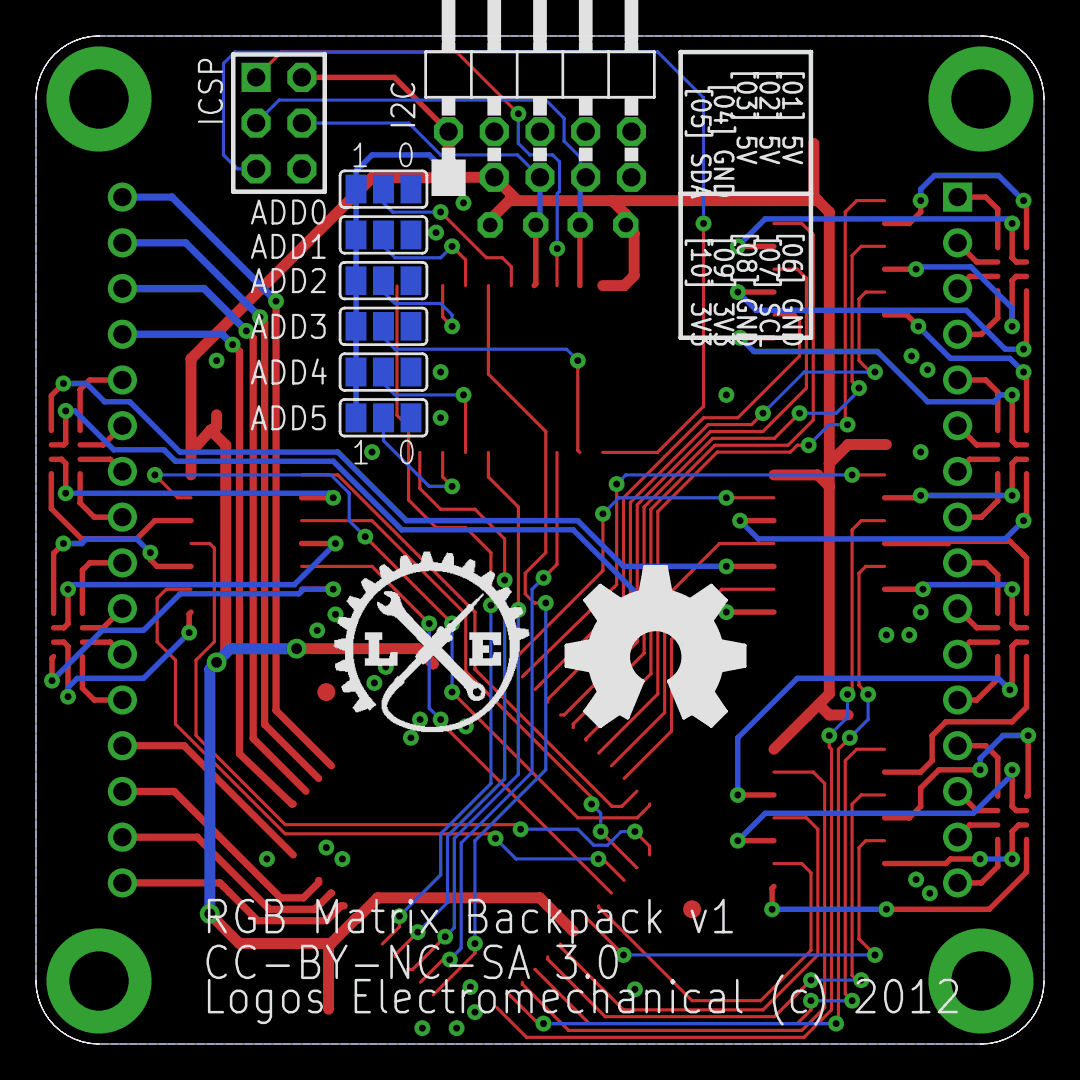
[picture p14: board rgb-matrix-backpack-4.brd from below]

Board: 2 copper layers, 56.0 x 56.0 mm, 38 parts (10 on the bottom side), 97 nets.

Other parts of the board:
U$1: LOGO-SM
U$4, U$5: FIDUCIAL_G10

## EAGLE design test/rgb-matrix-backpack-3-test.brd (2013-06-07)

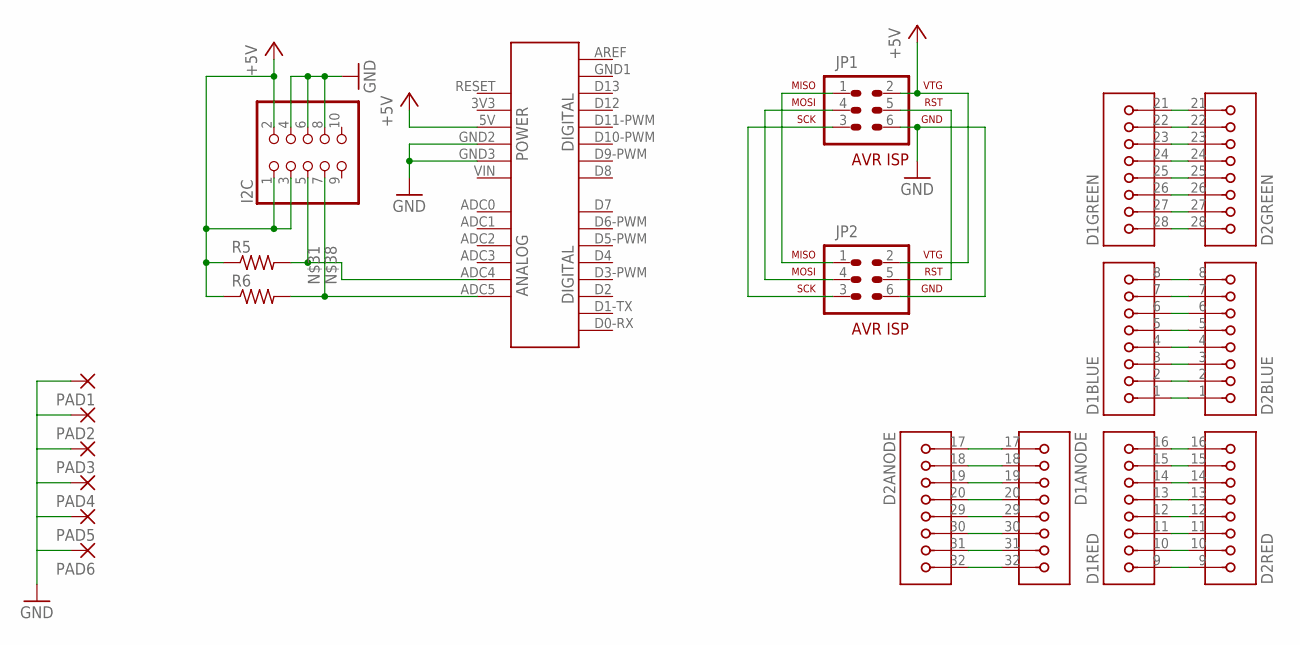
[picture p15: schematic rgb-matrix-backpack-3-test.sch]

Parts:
D1, D2: 60MM-8X8-RGB-LED-ARRAY; 60MM-8X8-RGB-MATRIX
I2C: PINHD-2X5_2.54-90°; 2X05/90
JP1, JP2: AVR-ISP-6
PAD1, PAD2, PAD3, PAD4, PAD5, PAD6: 1,6/0,8
R5, R6: R-US_R0603; R0603
SHIELD1: 2009

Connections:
+5V: I2C.1, I2C.2, I2C.3, JP1.2, JP2.2, R5.1, R6.1, SHIELD1.5V
GND: I2C.4, I2C.6, I2C.8, JP1.6, JP2.6, PAD1.1, PAD2.1, PAD3.1, PAD4.1, PAD5.1, PAD6.1, SHIELD1.GND2, SHIELD1.GND3
unnamed: D1.17 (1), D2.17 (1)
unnamed: D1.18 (2), D2.18 (2)
unnamed: D1.19 (3), D2.19 (3)
unnamed: D1.20 (4), D2.20 (4)
unnamed: D1.29 (5), D2.29 (5)
unnamed: D1.30 (6), D2.30 (6)
unnamed: D1.31 (7), D2.31 (7)
unnamed: D1.32 (8), D2.32 (8)
unnamed: D1.1, D2.1
unnamed: D1.2, D2.2
unnamed: D1.3, D2.3
unnamed: D1.4, D2.4
unnamed: D1.5, D2.5
unnamed: D1.6, D2.6
unnamed: D1.7, D2.7
unnamed: D1.8, D2.8
unnamed: D1.9 (1), D2.9 (1)
unnamed: D1.10 (2), D2.10 (2)
unnamed: D1.11 (3), D2.11 (3)
unnamed: D1.12 (4), D2.12 (4)
unnamed: D1.13 (5), D2.13 (5)
unnamed: D1.14 (6), D2.14 (6)
unnamed: D1.15 (7), D2.15 (7)
unnamed: D1.16 (8), D2.16 (8)
unnamed: D1.28 (1), D2.28 (1)
unnamed: D1.27 (2), D2.27 (2)
unnamed: D1.26 (3), D2.26 (3)
unnamed: JP1.1, JP2.1
unnamed: D1.25 (4), D2.25 (4)
unnamed: D1.24 (5), D2.24 (5)
unnamed: I2C.5, R5.2, SHIELD1.ADC4
unnamed: D1.23 (6), D2.23 (6)
unnamed: D1.22 (7), D2.22 (7)
unnamed: D1.21 (8), D2.21 (8)
unnamed: JP1.5, JP2.5
unnamed: I2C.7, R6.2, SHIELD1.ADC5
SCL: JP1.3, JP2.3
SDA: JP1.4, JP2.4

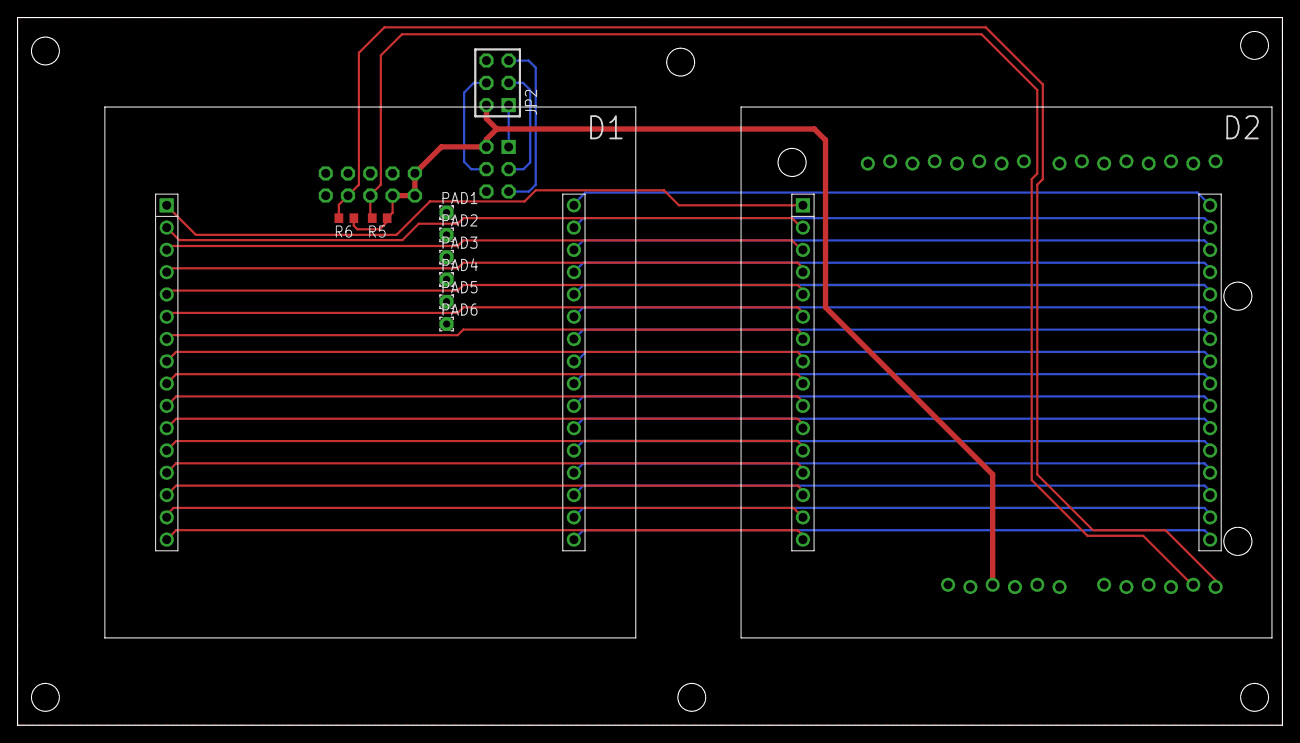
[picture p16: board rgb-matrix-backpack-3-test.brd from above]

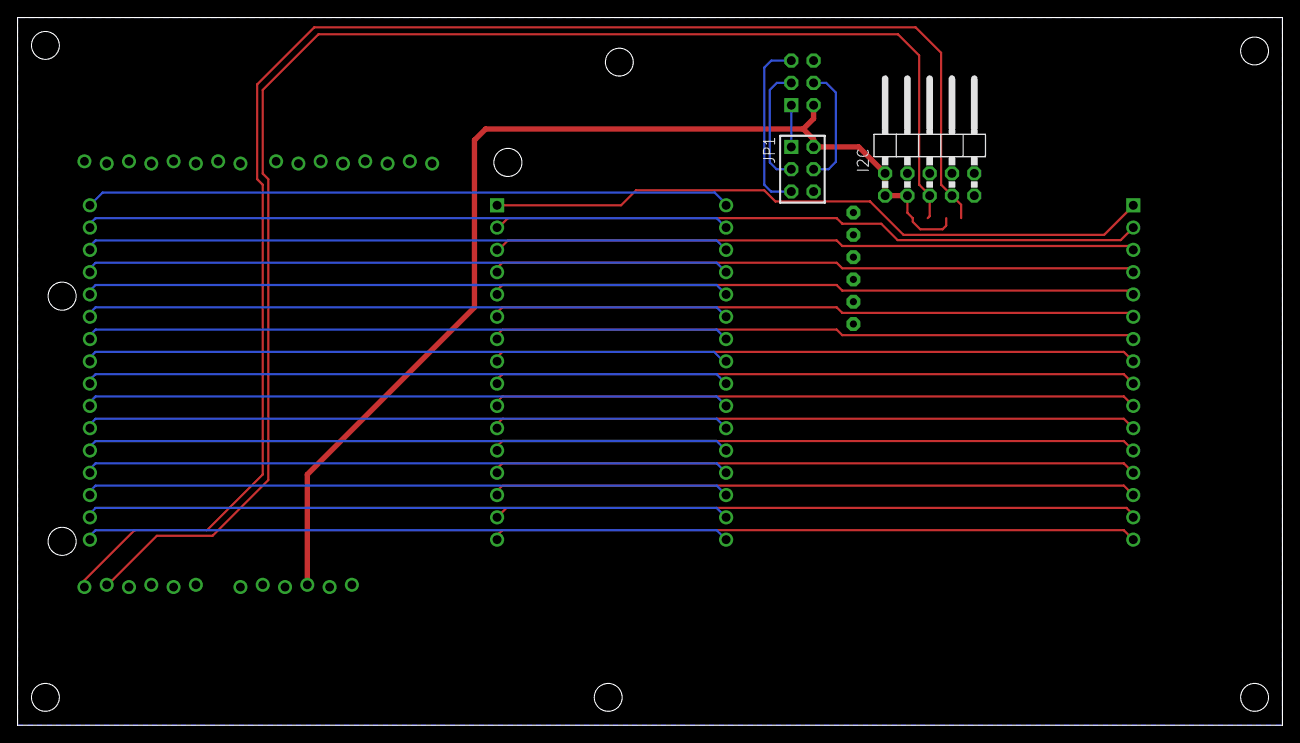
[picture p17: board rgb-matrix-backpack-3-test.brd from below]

Board: 2 copper layers, 144.1 x 80.6 mm, 14 parts (2 on the bottom side), 40 nets.

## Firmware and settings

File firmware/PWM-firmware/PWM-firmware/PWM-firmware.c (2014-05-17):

/*
 * PWM_firmware.c
 *
 * Created: 4/13/2014 10:03:55 PM
 *  Author: Pierce
 */ 

#include <stdio.h>
#include <stdint.h>
#include <stdlib.h>
#include <avr/io.h>
#include <avr/eeprom.h>
#include <avr/interrupt.h>
#include <util/delay.h>
#include "RGB-Matrix-protocol.h"

#define BUFLEN	200
#define OUTLEN	192
#define PWM_ALL	OCR1A	 
#define PWM_RED	OCR1B
#define PWM_GRN	OCR2B
#define PWM_BLU	OCR2A

uint8_t getAddress (void);
void init (uint8_t * in, uint8_t inlen, uint8_t * out, uint8_t outlen, uint8_t address);
void clearBuf (uint8_t * buf, uint8_t len);
void copyGRBBuf (uint8_t * in, uint8_t * out);
void copy3BitBuf (uint8_t * in, uint8_t * out);

uint8_t inbuf[BUFLEN];
uint8_t output[OUTLEN];
uint8_t inbufPtr;
uint8_t cmd = 0;
void inline doTick (void);

uint16_t pwmCtr;
uint8_t stopFlag = 1;

ISR(TWI_SLAVE_vect) {
	//volatile uint8_t dummy;
	
	if (TWSSRA & _BV(TWDIF)) {						// if we have a data value, put it in the buffer
		inbuf[inbufPtr] = TWSD;						// read in the data
		TWSCRB = _BV(TWCMD0) | _BV(TWCMD1);			// ACK the byte
		inbufPtr++;									// increment the buffer pointer
	} 
	if (TWSSRA & _BV(TWASIF)) {
		if (TWSSRA & _BV(TWAS)) {					// if we have an address, reset the input buffer
			TWSCRB = _BV(TWCMD0) | _BV(TWCMD1);		// ACK the byte; this is first since all our house keeping takes less 
													// time than getting our next byte, so we should do it first to speed the transaction
			TWSSRA |= _BV(TWASIF);					// clear the address match flag
			if (stopFlag) {							// if the last interrupt was caused by a stop condition, clear the buffer
				inbufPtr = 0;
				clearBuf(inbuf, (uint8_t)BUFLEN);
				stopFlag = 0;
			}
		} else {									// if we have a stop condition, set the command to the first byte
			TWSCRB = _BV(TWCMD0) | _BV(TWCMD1);		// ACK the byte
			TWSSRA |= _BV(TWASIF);					// clear the address match flag
			if (inbufPtr) cmd = inbuf[0];
			stopFlag++;
		}
	} 
	if ((TWSSRA & _BV(TWBE)) || 
		(TWSSRA & _BV(TWC))) {						// if we have an error, reset the input buffer and remove the error
		inbufPtr = 0;
		clearBuf(inbuf, (uint8_t)BUFLEN);
		stopFlag++;
		TWSSRA |= _BV(TWBE);						// reset the bus error
		TWSSRA |= _BV(TWC);							// reset the bus collision
		TWSCRB = _BV(TWCMD0) | _BV(TWCMD1);			// ACK the byte
	}
}


int main(void) {
		
	init(inbuf, (uint8_t)BUFLEN, output, (uint8_t)OUTLEN, getAddress());
	
    while(1) {
		doTick();
        switch (cmd) {
			case RGB_CMD_ALL_DIM:
				PWM_ALL = inbuf[1];
			break;
			case RGB_CMD_BLU_DIM:
				PWM_BLU = inbuf[1];
			break;
			case RGB_CMD_GRN_DIM:
				PWM_GRN = inbuf[1];
			break;
			case RGB_CMD_RED_DIM:
				PWM_RED = inbuf[1];
			break;
			case RGB_CMD_24_GRB_DATA:
				copyGRBBuf(inbuf, output);
				cmd = 0;
			break;
			case RGB_CMD_3_RGB_DATA:
				copy3BitBuf(inbuf, output);
				cmd = 0;
			break;
			default:	
			break;
		}
    }
}

uint8_t getAddress (void) {

	//uint8_t pa = 0;
	//uint8_t pb = 0;
	uint8_t result = 0x81;	// set the top bit of the address in order to avoid stomping on the general call address
							// set the bottom bit so that it responds to the general call address 

	// set all lines to inputs
	DDRA = 0;
	DDRB = 0;
	
	// turn on the pull-ups for all address lines in 
	// order to force a default address
	//PUEA = 0xa5;
	//PUEB = 0x05;
	
	// read the input ports
	//pa = PINA;
	//pb = PINB;
	
	// map address pins into an address
	if (PINA & _BV(5)) result += 0x02;	// address bit 0
	if (PINA & _BV(7)) result += 0x04;	// address bit 1
	if (PINA & _BV(0)) result += 0x08;	// address bit 2
	if (PINB & _BV(2)) result += 0x10;	// address bit 3
	if (PINA & _BV(2)) result += 0x20;	// address bit 4
	if (PINA & _BV(1)) result += 0x40;	// address bit 5
	
	// turn off the pull-ups
	//PUEA = 0;
	//PUEB = 0;
	
	return result;
}

void init (uint8_t * in, uint8_t inlen, uint8_t * out, uint8_t outlen, uint8_t address) {
	
	DDRA = 0xaf;	// set everything except the TWI pins to output 
	DDRB = 0x04;	// set everything to outputs except clock lines & reset
	
	// set up PWM outputs
	TCCR1A = _BV(COM1A0) | _BV(COM1A1) | _BV(COM1B0) | _BV(COM1B1) | _BV(WGM10);
	TCCR2A = _BV(COM2A0) | _BV(COM2A1) | _BV(COM2B0) | _BV(COM2B1) | _BV(WGM20);
	TCCR1B = _BV(WGM12)	| _BV(CS10);
	TCCR2B = _BV(WGM22) | _BV(CS20);
	TOCPMSA0 = _BV(TOCC1S0);	
	TOCPMSA1 = _BV(TOCC4S0) | _BV(TOCC6S1) | _BV(TOCC7S1);
	TOCPMCOE = _BV(TOCC1OE) | _BV(TOCC4OE) | _BV(TOCC6OE) | _BV(TOCC7OE);
	PWM_ALL = 0xff;
	PWM_BLU = 0xff;
	PWM_GRN = 0xff;
	PWM_RED = 0xff;
	
	// set up the TWI interface and clear the buffers
	TWSA = address;
	TWSCRA = _BV(TWDIE) | _BV(TWASIE) | _BV(TWEN) | _BV(TWSIE); // | _BV(TWSME);
	//TWSCRB = _BV(TWCMD0) | _BV(TWCMD1);
	clearBuf(in, inlen);
	clearBuf(out, outlen);
	
	// set up SPI output
	SPCR = _BV(SPE) | _BV(MSTR);	// turn on the SPI bus in master mode
	SPSR = _BV(SPI2X);				// turn it up to max speed (clk/2)
	REMAP = _BV(SPIMAP);			// remap the SPI pins to alternates
	
	DDRA = 0xaf;	// set everything except the TWI pins to output (makes sure PA0 is an output)
	PUEA |= _BV(4) | _BV(6);
	
	// turn on interrupts and away we go
	sei();
}

void clearBuf (uint8_t * buf, uint8_t len) {
	int i;
	for (i = 0; i < len; i++) buf[i] = 0;
}

void copyGRBBuf(uint8_t * in, uint8_t * out)
{
	uint8_t row, col;
	
	for (row = 0; row < 8; row++) {
		for (col = 0; col < 8; col++) {
			out[(15-col) + (row * 24)]		= in[((col*3) + 1) + (row * 24)] >> 2;	// copy the green (order is flipped)
			out[col + (row * 24)]			= in[((col*3) + 3) + (row * 24)] >> 2;	// copy the blue
			out[(col + 16) + (row * 24)]	= in[((col*3) + 2) + (row * 24)] >> 2;	// copy the red
		}
	}
}

// Copy the R...G...B... bit string from a buffer encoded for the original buffer
// to the GRBGRBGRB... byte string required for PWM generation in this code
void copy3BitBuf(uint8_t * in, uint8_t * out)
{
	uint8_t row, col;
	
	for (row = 0; row < 8; row++) {
		for (col = 0; col < 8; col++) {
			(in[row + 1] & _BV(col))	? out[((col + 16) + (row * 24))] = 0x3f	: (out[((col + 16) + (row * 24))] = 0);		// grab the red (first eight bytes of input)
			(in[row + 9] & _BV(col))	? out[(col + 8) + (row * 24)] = 0x3f	: (out[(col + 8) + (row * 24)] = 0);		// grab the green (next eight bytes of input)
			(in[row + 17] & _BV(col))	? out[(col) + (row * 24)] = 0x3f		: (out[(col) + (row * 24)] = 0);			// grab the green (next eight bytes of input)
		}
	}
}

void inline doTick(void) {
	uint8_t select = 0;
	uint8_t rowSelect = 0;
	register uint8_t out;
	
	for (rowSelect = 0; rowSelect < 8; rowSelect++) {
		select = rowSelect * 24;
		for (pwmCtr = 0; pwmCtr < 64; pwmCtr++) {
			// Since we're overloading what would otherwise be the MISO line to be the latch line, we need to disable & re-enable SPI every cycle
			SPCR = 0;
			PORTA &= ~_BV(0);	
			PORTA |= _BV(0);
			SPCR = _BV(SPE) | _BV(MSTR);	// turn on the SPI bus in master mode
			
			//PORTA |= _BV(0);					// drive the latch line high
			//SPDR = ~_BV(rowSelect);
			//PORTA &= ~_BV(0);					// clear the latch line
			// write out the blue LEDs
			SPDR = ~_BV(rowSelect);
			out = 0xff;
			(output[select + 0] <= pwmCtr)	? (out |= _BV(0)) : (out &= ~_BV(0));
			(output[select + 1] <= pwmCtr)	? (out |= _BV(1)) : (out &= ~_BV(1));
			(output[select + 2] <= pwmCtr)	? (out |= _BV(2)) : (out &= ~_BV(2));
			(output[select + 3] <= pwmCtr)	? (out |= _BV(3)) : (out &= ~_BV(3));
			(output[select + 4] <= pwmCtr)	? (out |= _BV(4)) : (out &= ~_BV(4));
			(output[select + 5] <= pwmCtr)	? (out |= _BV(5)) : (out &= ~_BV(5));
			(output[select + 6] <= pwmCtr)	? (out |= _BV(6)) : (out &= ~_BV(6));
			(output[select + 7] <= pwmCtr)	? (out |= _BV(7)) : (out &= ~_BV(7));
			
			SPDR = out;
			// write out the green LEDs
			out = 0xff;
			(output[select + 8] <= pwmCtr)	? (out |= _BV(0)) : (out &= ~_BV(0));
			(output[select + 9] <= pwmCtr)	? (out |= _BV(1)) : (out &= ~_BV(1));
			(output[select + 10] <= pwmCtr)	? (out |= _BV(2)) : (out &= ~_BV(2));
			(output[select + 11] <= pwmCtr)	? (out |= _BV(3)) : (out &= ~_BV(3));
			(output[select + 12] <= pwmCtr)	? (out |= _BV(4)) : (out &= ~_BV(4));
			(output[select + 13] <= pwmCtr)	? (out |= _BV(5)) : (out &= ~_BV(5));
			(output[select + 14] <= pwmCtr)	? (out |= _BV(6)) : (out &= ~_BV(6));
			(output[select + 15] <= pwmCtr)	? (out |= _BV(7)) : (out &= ~_BV(7));
			SPDR = out;
			// write out the red LEDs
			out = 0xff;
			(output[select + 16] <= pwmCtr)	? (out |= _BV(0)) : (out &= ~_BV(0));
			(output[select + 17] <= pwmCtr)	? (out |= _BV(1)) : (out &= ~_BV(1));
			(output[select + 18] <= pwmCtr)	? (out |= _BV(2)) : (out &= ~_BV(2));
			(output[select + 19] <= pwmCtr)	? (out |= _BV(3)) : (out &= ~_BV(3));
			(output[select + 20] <= pwmCtr)	? (out |= _BV(4)) : (out &= ~_BV(4));
			(output[select + 21] <= pwmCtr)	? (out |= _BV(5)) : (out &= ~_BV(5));
			(output[select + 22] <= pwmCtr)	? (out |= _BV(6)) : (out &= ~_BV(6));
			(output[select + 23] <= pwmCtr)	? (out |= _BV(7)) : (out &= ~_BV(7));
			SPDR = out;
			while (!(SPSR & _BV(SPIF)));	// wait for the last SPI transmission to finish
			//PORTB |= _BV(1);			// drive the latch line high
		}
	}
}

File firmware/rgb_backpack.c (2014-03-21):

// low fuse setting:		0xef
// high fuse setting:		0xdf
// extended fuse setting: 	0xff
// avrdude fuse command line: "avrdude -c usbtiny -p t2313 -Ulfuse:w:0xe4:m -Uhfuse:w:0xdf:m -Uefuse:w:0xff:m"
// avrdude flash command line: "avrdude  -c usbtiny -p t2313 -Uflash:w:rgb_backpack.hex"
// avrdude whole command line: "avrdude -c usbtiny -p t2313 -Ulfuse:w:0xe4:m -Uhfuse:w:0xdf:m -Uefuse:w:0xff:m -Uflash:w:rgb_backpack.hex"

#include <avr/io.h>    		// for PORTx, PINx, DDRx, etc.
#include <avr/interrupt.h>  // there will be interrupts
#include <stdint.h>			// for all those tasty integer types
#include <avr/sfr_defs.h>	// some useful stuff for manipulation of registers
#include <util/delay.h>
#include <util/twi.h>		// bitmask for I2C
#include "usiTwiSlave.h"

// Define the address setting jumpers

#define ADDL_PORT	PINB
#define ADDH_PORT	PIND

// Define the lines for driving the backpack chip

#define DRV_PORT 	PORTD
#define DRV_CS		PD6
#define DRV_RD		PD5
#define DRV_WR		PD2
#define DRV_DATA	PD1

// Define commands

#define CMD_DISABLE		0x00
#define CMD_ENABLE		0x01
#define CMD_LEDOFF		0x02
#define CMD_LEDON		0x03
#define CMD_BLINKON		0x08
#define CMD_BLINKOFF	0x09
#define CMD_SLAVE		0x10
#define CMD_MASTER_RC	0x18
#define CMD_MASTER_EXT	0x1c
#define CMD_COM_N8		0x20
#define CMD_COM_N16		0x24
#define CMD_COM_P8		0x28
#define CMD_COM_P16		0x2c

void init (void);
void shiftOut (uint8_t *bytes); 
void shiftCmd (uint8_t cmd);
void shiftByte (uint8_t byte);
void shiftBuffer (void);

int main (void) {

	
	init();
	
	while (1) {
		if(usiTwiDataInReceiveBuffer()) {
			_delay_ms(10.0);
			shiftBuffer();
		}
	}
	
}

void init (void) {
	uint8_t address = 0x00;
	//uint8_t bytes[24] = {0,0,0,0,0,0,0,0,0,0,0,0,0,0,0,0,0,0,0,0,0,0,0,0};
	
	// set up ports
	DDRD = 0xe6;
	DDRB = 0xe9;
	
	// initialize driver
	DRV_PORT |= (_BV(DRV_CS) | _BV(DRV_WR) | _BV(DRV_RD) | _BV(DRV_DATA));
	//shiftCmd(CMD_MASTER_RC);
	shiftCmd(CMD_MASTER_EXT);
	shiftCmd(CMD_COM_P8);
	shiftCmd(CMD_ENABLE);
	shiftCmd(CMD_LEDON);
	
	// start the timer
	TCCR1A 	= _BV(COM1A0);					// Toggle on match, channel A
	TCCR1B 	= _BV(WGM12) | _BV(CS10);		// CTC mode, no prescaling
	OCR1A	= 3;							// 1 MHz		
	
	// read address
	PORTB |= (_BV(PB4)|_BV(PB2)|_BV(PB1));			// set pullups high to enable default address
	PORTD |= (_BV(PD0)|_BV(PD3)|_BV(PD4));			// set pullups high to enable default address
	if ((PINB & _BV(PB4)) != 0) address |= 0x01; 
	if ((PINB & _BV(PB2)) != 0) address |= 0x02;
	if ((PINB & _BV(PB1)) != 0) address |= 0x04;
	if ((PIND & _BV(PD0)) != 0) address |= 0x08; 
	if ((PIND & _BV(PD3)) != 0) address |= 0x10;
	if ((PIND & _BV(PD4)) != 0) address |= 0x20;
	address |= 0x40;	// set the high bit, so we don't squat on the broadcast address (0x00)
	
	// check address
	//bytes[0] = address;
	//bytes[1] = ~address;
	//shiftOut(bytes);
	
	// initialize USI for I2C slave
	usiTwiSlaveInit(address);
	
	// enable interrupts
	sei();
	return;
}

void shiftOut (uint8_t *bytes) {

	uint8_t i, j, val;
	
	DRV_PORT &= ~_BV(DRV_CS);		// enable the serial bus
	DRV_PORT &= ~_BV(DRV_WR);
	DRV_PORT |= _BV(DRV_WR);		// clock in a one
	DRV_PORT &= ~_BV(DRV_DATA);	// set data output to zero
	DRV_PORT &= ~_BV(DRV_WR);
	DRV_PORT |= _BV(DRV_WR);		// clock in a zero
	DRV_PORT |= _BV(DRV_DATA);
	DRV_PORT &= ~_BV(DRV_WR);
	DRV_PORT |= _BV(DRV_WR);		// clock in a one	
	DRV_PORT &= ~_BV(DRV_DATA);	// set data output to zero
	DRV_PORT &= ~_BV(DRV_WR);
	
	// set the address to 0x00
	for (i = 0; i < 7; i++)  {
		DRV_PORT &= ~_BV(DRV_WR);
		DRV_PORT |= _BV(DRV_WR);
	}
	
	// shift the data
	for (i = 0; i < 24; i++) {
		val = bytes[i];
		for (j = 0; j < 8; j++)  {
			DRV_PORT &= ~_BV(DRV_WR);	// prep for next bit
			if (val & (1 << j)) {
				DRV_PORT |= _BV(DRV_DATA);
			} else {
				DRV_PORT &= ~_BV(DRV_DATA);
			}
			DRV_PORT |= _BV(DRV_WR);	// clock in the next bit
		}
	}
	DRV_PORT |= _BV(DRV_WR);
	DRV_PORT |= _BV(DRV_DATA);
	DRV_PORT |= _BV(DRV_CS);		// end transmission
	return;
}

void shiftCmd (uint8_t cmd) {
	uint8_t i;

	DRV_PORT &= ~_BV(DRV_CS);		// enable the serial bus
	_delay_us(1.0);	
	DRV_PORT &= ~_BV(DRV_WR);
	_delay_us(1.0);
	DRV_PORT |= _BV(DRV_WR);		// clock in a one
	_delay_us(1.0);
	DRV_PORT &= ~_BV(DRV_DATA);	// set data output to zero
	DRV_PORT &= ~_BV(DRV_WR);
	_delay_us(1.0);
	DRV_PORT |= _BV(DRV_WR);		// clock in a zero
	_delay_us(1.0);
	DRV_PORT &= ~_BV(DRV_WR);
	_delay_us(1.0);
	DRV_PORT |= _BV(DRV_WR);		// clock in a zero

	for (i = 0; i < 8; i++)  {
		DRV_PORT &= ~_BV(DRV_WR);	// prep for next bit
		if (cmd & (1 << (7 - i))) {
			DRV_PORT |= _BV(DRV_DATA);
		} else {
			DRV_PORT &= ~_BV(DRV_DATA);
		}
		_delay_us(1.0);
		DRV_PORT |= _BV(DRV_WR);	// clock in the next bit
		_delay_us(1.0);
	}
	DRV_PORT &= ~_BV(DRV_DATA);	// set data output to zero
	DRV_PORT &= ~_BV(DRV_WR);
	_delay_us(1.0);
	DRV_PORT |= _BV(DRV_WR);		// shift out a trailing zero
	_delay_us(1.0);
	DRV_PORT |= _BV(DRV_DATA);
	DRV_PORT |= _BV(DRV_CS);		// end transmission
	return;
}

void shiftBuffer (void) {

	uint8_t i, j, val;
	
	DRV_PORT &= ~_BV(DRV_CS);		// enable the serial bus
	DRV_PORT &= ~_BV(DRV_WR);
	DRV_PORT |= _BV(DRV_WR);		// clock in a one
	DRV_PORT &= ~_BV(DRV_DATA);	// set data output to zero
	DRV_PORT &= ~_BV(DRV_WR);
	DRV_PORT |= _BV(DRV_WR);		// clock in a zero
	DRV_PORT |= _BV(DRV_DATA);
	DRV_PORT &= ~_BV(DRV_WR);
	DRV_PORT |= _BV(DRV_WR);		// clock in a one	
	DRV_PORT &= ~_BV(DRV_DATA);	// set data output to zero
	DRV_PORT &= ~_BV(DRV_WR);
	
	// set the address to 0x00
	for (i = 0; i < 7; i++)  {
		DRV_PORT &= ~_BV(DRV_WR);
		DRV_PORT |= _BV(DRV_WR);
	}
	
	// shift the data
	for (i = 0; i < 24; i++) {
		val = usiTwiReceiveByte();
		for (j = 0; j < 8; j++)  {
			DRV_PORT &= ~_BV(DRV_WR);	// prep for next bit
			if (val & (1 << j)) {
				DRV_PORT |= _BV(DRV_DATA);
			} else {
				DRV_PORT &= ~_BV(DRV_DATA);
			}
			DRV_PORT |= _BV(DRV_WR);	// clock in the next bit
		}
	}
	DRV_PORT |= _BV(DRV_WR);
	DRV_PORT |= _BV(DRV_DATA);
	DRV_PORT |= _BV(DRV_CS);		// end transmission
	return;

}

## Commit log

2013-06-07 Checking it all in for the first time
    [rgb-matrix-backpack-3-test.brd, rgb-matrix-backpack-3-test.sch, rgb-matrix-backpack-4.brd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]
2013-06-10 Initial cleanup and minor fix to makefile
    [rgb-matrix-backpack-4.brd, rgb-matrix-backpack-4.sch]
2014-03-21 Moved the board files back where they belong
    [rgb-matrix-backpack-4.brd, rgb-matrix-backpack-4.sch]
2014-05-14 This is the new version, now with PWM!
    [rgb-matrix-backpack-5.brd, rgb-matrix-backpack-5.sch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]
2014-05-17 Final changes to get the firmware working.
    [rgb-matrix-backpack-5a.sch]

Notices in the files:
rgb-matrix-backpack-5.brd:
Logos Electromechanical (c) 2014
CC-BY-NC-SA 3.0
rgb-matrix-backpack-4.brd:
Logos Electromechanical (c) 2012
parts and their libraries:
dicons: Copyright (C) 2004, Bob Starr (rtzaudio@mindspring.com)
